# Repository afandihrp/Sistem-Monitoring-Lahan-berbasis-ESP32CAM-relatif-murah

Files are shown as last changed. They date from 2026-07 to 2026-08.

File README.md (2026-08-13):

# Sistem Monitoring Keamanan & Bounding Box AI Berbasis ESP32-CAM & Sensor Getar

Sistem monitoring keamanan pintar berbasis IoT yang mengintegrasikan kamera **ESP32-CAM**, sensor gerak PIR multi-arah, **Node Sensor Getar (Vibration Sensor Node)** dengan kontrol relay HTTP, motor servo pemutar kamera otomatis, kecerdasan buatan (**AI YOLO 11**) untuk deteksi dan pelacakan manusia (*Object Tracking* berbasis *Proportional Controller*), penyimpanan terpusat **SQLite Database**, serta bot Telegram untuk notifikasi instan berupa foto snapshot dan rekaman video MP4.

LINK GITHUB https://github.com/afandihrp/Sistem-Monitoring-Lahan-berbasis-ESP32CAM-relatif-murah.git

---

## 📋 Daftar Isi
1. [Panduan Pengoperasian Sistem (System Operation Guide)](#panduan-pengoperasian-sistem)
   * [1. Autentikasi & Login Pengguna](#1-autentikasi--login-pengguna)
   * [2. Pemilihan Kamera & Feed Live Streaming](#2-pemilihan-kamera--feed-live-streaming)
   * [3. Kontrol Pergerakan Manual Servo (PTZ)](#3-kontrol-pergerakan-manual-servo-ptz)
   * [4. Modal Pengaturan Terpadu (Hardware, PTZ & AI)](#4-modal-pengaturan-terpadu-hardware-ptz--ai)
   * [5. Peninjauan Event Logs & Pemutaran Video Rekaman MP4](#5-peninjauan-event-logs--pemutaran-video-rekaman-mp4)
   * [6. Kontrol & Pengujian Node Sensor Getar](#6-kontrol--pengujian-node-sensor-getar)
   * [7. Penerimaan Notifikasi Peringatan di Bot Telegram](#7-penerimaan-notifikasi-peringatan-di-bot-telegram)
2. [Panduan Instalasi Aplikasi (Server-Side)](#panduan-instalasi-aplikasi)
   * [Instalasi pada Linux (Ubuntu, Linux Mint, Debian)](#1-instalasi-pada-linux-ubuntu-linux-mint--debian-based)
   * [Instalasi pada Windows (Windows 10 / 11)](#2-instalasi-pada-windows-windows-10--11)
   * [Startup Scripts Opsi Cepat (Windows & Linux)](#3-startup-scripts-opsi-cepat-windows-batch--linux-shell)
3. [Setup Hardware & Perkabelan](#setup-hardware-perkabelan)
   * [Pinout ESP32-CAM (AI-Thinker)](#1-pinout-esp32-cam-ai-thinker)
   * [Pinout Node Sensor Getar](#2-pinout-node-sensor-getar-vibration-sensor-node)
   * [Konfigurasi Arduino IDE](#3-konfigurasi-arduino-ide)
   * [Skematik Rangkaian & Desain Hardware Node](#4-skematik-rangkaian--desain-hardware-node)
   * [Dokumentasi Fisik & Realisasi PCB Hardware](#5-dokumentasi-fisik--realisasi-pcb-hardware)
4. [Fitur Utama](#fitur-utama)
   * [Pelacakan Gerakan Otomatis (PIR)](#1-pelacakan-gerakan-otomatis-pir-triggered-servo-rotation)
   * [Node Sensor Getar & HTTP Relay API](#2-node-sensor-getar--http-relay-control-api)
   * [Deteksi Manusia YOLO 11 & P-Controller](#3-deteksi-manusia-yolo-11--pure-proportional-object-tracking)
   * [Mode Sapuan Servo (Sweep & Auto-Return)](#4-mode-sapuan-servo-servo-sweep--auto-return)
   * [Protokol Streaming Biner 16-Bit](#5-protokol-streaming-biner-16-bit--dynamic-chunking)
   * [Penyimpanan Terpusat SQLite Database](#6-penyimpanan-terpusat-sqlite-database-camera_datadb)
   * [Panel Kontrol Kiosk UI Modern](#7-panel-kontrol-kiosk-ui-modern)
   * [Integrasi Bot Telegram & Alert Log](#8-integrasi-bot-telegram--alert-log)
5. [Arsitektur Sistem](#arsitektur-sistem)
6. [Alur Kerja Deteksi Keamanan & Flowchart](#alur-kerja-deteksi-keamanan)
7. [Dokumentasi API & Skema Payload WebSocket](#dokumentasi-api--skema-payload-websocket)
   * [HTTP REST API Endpoint Registry](#1-http-rest-api-endpoint-registry)
   * [Payload WebSocket (ESP32-CAM <-> Backend)](#2-skema-payload-websocket-esp32-cam---backend-nodejs)
   * [Payload WebSocket (Backend <-> Kiosk UI)](#3-skema-payload-websocket-backend-nodejs---kiosk-ui-frontend)
8. [Demo & Tampilan Antarmuka](#demo-tampilan-antarmuka)

---

## 📱 Panduan Pengoperasian Sistem (System Operation Guide)

Panduan langkah demi langkah bagi pengguna akhir (*end-user*) untuk mengoperasikan seluruh antarmuka sistem Kiosk UI, mengontrol perangkat kamera, memutar video rekaman, hingga menerima peringatan keamanan:

---

### 1. Autentikasi & Login Pengguna
1. **Perilaku Autentikasi Berbasis Jaringan (Smart IP-Based Bypass)**:
   * 🟢 **Akses Jaringan Lokal (LAN / Wi-Fi Lokal / Localhost)**:
     * Jika pengguna mengakses portal dari jaringan Wi-Fi/LAN lokal (rentang IP privat `127.0.0.1`, `192.168.x.x`, `10.x.x.x`, atau `172.16-31.x.x`), sistem **secara otomatis membebaskan login** (*Bypass Authentication*). Pengguna akan langsung diarahkan ke Dashboard Pemantauan Utama tanpa perlu memasukkan kata sandi.
   * 🔴 **Akses Jaringan Luar (Tailscale Funnel / VPN Tunneling / IP Publik)**:
     * Jika pengguna mengakses sistem secara *remote* dari luar jaringan lokal menggunakan **Tailscale Funnel** (`runFunnel`), VPN *Tunneling*, atau rute publik eksternal, sistem **secara otomatis mewajibkan autentikasi login** demi mencegah akses tanpa izin.
2. Buka peramban (*browser*) dan akses URL portal sistem:
   * **Akses Nginx (Rekomendasi)**: `http://localhost` (atau IP Lokal server).
   * **Akses Remote Tailscale Funnel**: `https://<subdomain-tailscale-anda>.ts.net`.
   * **Akses Langsung Dev Server**: `http://localhost:5173`.
3. Masukkan kata sandi autentikasi sistem:
   * **Kata Sandi Default**: `admin` (kata sandi bawaan sistem).
   * **Kata Sandi Kustom**: Jika sudah diubah pada file environment `backendAndTelegramBot/.env`, masukkan kata sandi yang dikonfigurasi pada variabel `SYSTEM_PASSWORD` (atau `ADMIN_PASSWORD`).
4. Tekan tombol **Login** untuk menyimpan token autentikasi JWT aman (*HttpOnly Cookie*) dan membuka Dashboard Pemantauan Utama.

| Halaman Autentikasi Kiosk UI |
| :---: |
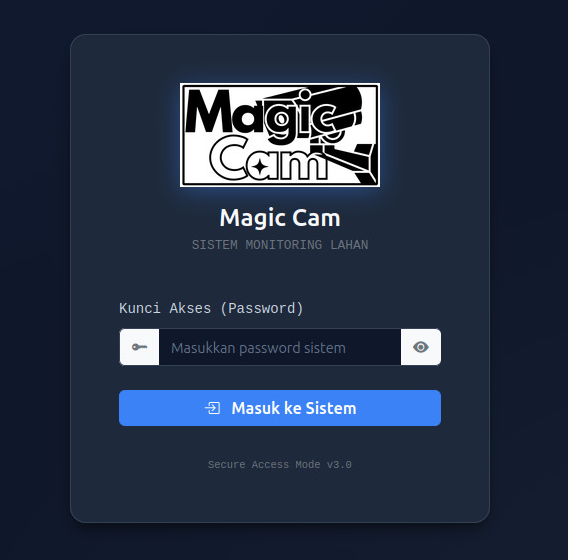
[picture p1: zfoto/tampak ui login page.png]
Tampak UI Login Page
|  |
| *Tampilan Halaman Autentikasi Pengguna (Login Page)* |

---

### 2. Pemilihan Kamera & Feed Live Streaming
1. **Melihat Video Streaming**: Setelah berhasil login, layar utama akan menampilkan tayangan langsung (*Live Stream*) beresolusi optimal dengan rasio 4:3.
2. **Memilih Kamera Aktif**: Jika terdapat lebih dari satu kamera ESP32-CAM terhubung, klik nama/tab kamera pada **Bilah Daftar Kamera (Active Camera List)** di bagian atas atau samping layar untuk berpindah tayangan.
3. **Memantau Indikator Status**:
   * **FPS Meter**: Menampilkan kecepatan *frame rate* per detik secara *real-time* di sudut video.
   * **Indikator Koneksi**: Memantau status hijau (*Connected*) atau merah (*Disconnected*) WebSocket backend gateway.
   * **Hitung Mundur Sapuan Servo**: Menampilkan jeda waktu menuju penyapuan sudut berikutnya.

| Dashboard Pemantauan Desktop | Dashboard Pemantauan Mobile |
| :---: | :---: |
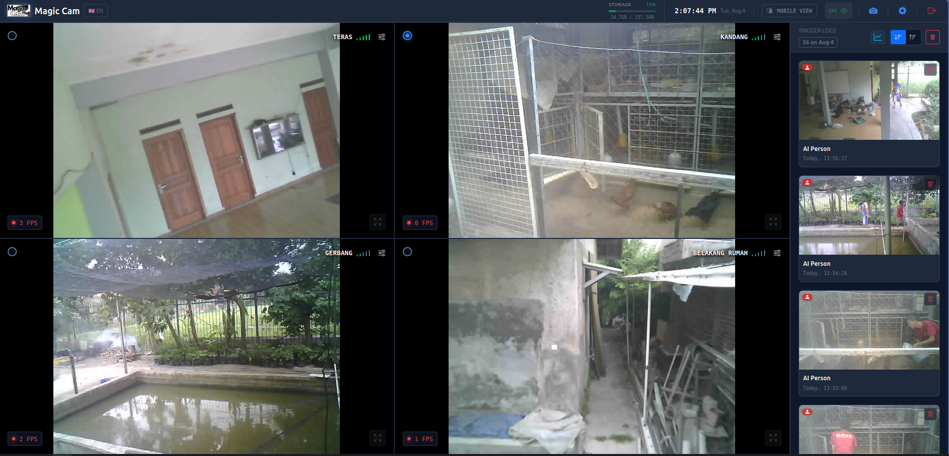
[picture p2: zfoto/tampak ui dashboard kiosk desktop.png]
Tampak UI Dashboard Kiosk Desktop
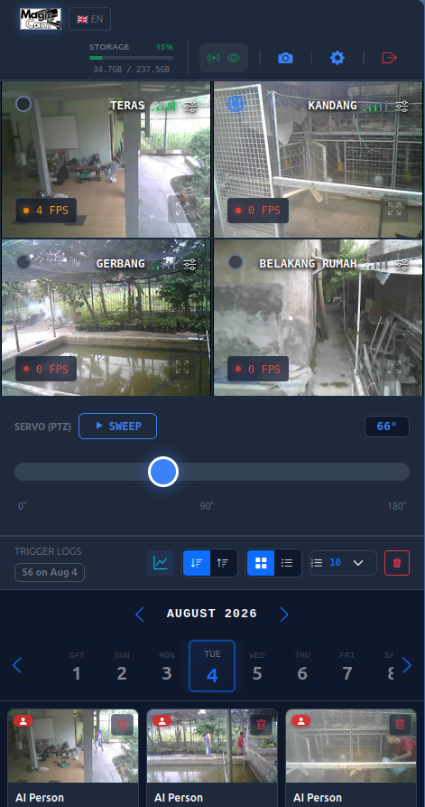
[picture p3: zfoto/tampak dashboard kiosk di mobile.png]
Tampak Dashboard Kiosk di Mobile
|  |  |
| *Dashboard Utama Kiosk UI (Desktop View)* | *Dashboard Utama Kiosk UI (Mobile View)* |

---

### 3. Kontrol Pergerakan Manual Servo (PTZ)
1. **Mengarahkan Kamera**: Gunakan tombol kontrol arah PTZ pada panel antarmuka untuk memutar kamera ESP32-CAM secara manual (sudut $0^\circ$ hingga $180^\circ$).
2. **Penyesuaian Sudut Presisi**: Geser *slider* sudut servo (*tilt/pan slider*) untuk menargetkan posisi pandang tertentu secara fleksibel dan cepat.
3. **Reset Posisi Awal**: Tekan tombol **Default Angle** untuk mengembalikan kamera ke sudut diam standar (misal $90^\circ$).

| Antarmuka Slider Servo Pan/Tilt PTZ |
| :---: |
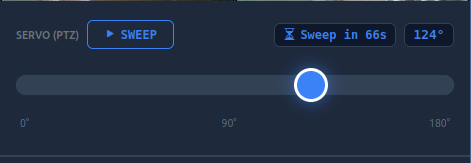
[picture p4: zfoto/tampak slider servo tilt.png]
Tampak Slider Servo Tilt
|  |
| *Tampilan Panel Kontrol Slider Sudut Motor Servo Pan/Tilt pada Kiosk UI* |

---

### 4. Modal Pengaturan Terpadu (Hardware, PTZ & AI)
Klik ikon **Settings (⚙️)** di bagian kanan atas layar untuk membuka modal konfigurasi terpadu:

#### A. Tab Hardware Kamera:
* **Pengaturan Citra**: Sesuaikan tingkat *Brightness* (Kecerahan), *Contrast* (Kontras), dan *Saturation* (Saturasi).
* **Koreksi Otomatis**: Aktifkan/nonaktifkan *Auto White Balance (AWB)* dan *Auto Exposure Control (AEC)*.
* **Efek & Flash**: Pilih *Special Effects* (seperti Grayscale / Negative) dan sesuaikan intensitas lampu sorot LED Flash.
* **Identitas Kamera**: Ubah nama alias lokasi kamera (misal *"Kamera Garasi Depan"*) berdasarkan alamat MAC unik.

#### B. Tab PTZ & Mode Sapuan Servo:
* **Mode Operasi Servo**:
  * **Sweep Mode**: Kamera akan menyapu area pemantauan secara berkala berdasarkan interval waktu.
  * **Auto Return Mode**: Kamera akan kembali ke sudut diam default setelah terpicu gerakan.
* **Timer Interval**: Tentukan interval penyapuan otomatis (misal `15s`, `30s`, atau `Off`).
* **Pemetaan Sudut PIR**: Tentukan sudut kemiringan servo khusus untuk setiap sensor PIR Kiri, Tengah, dan Kanan.

#### C. Tab Konfigurasi AI & Sistem:
* **Deteksi Manusia YOLO 11**: Aktifkan atau nonaktifkan sakelar inferensi AI deteksi manusia secara *real-time*.
* **Ambang Batas Kepercayaan (Confidence Threshold)**: Tentukan batas minimal skor deteksi AI sebelum memicu perekaman video dan notifikasi.

---

### 5. Peninjauan Event Logs & Pemutaran Video Rekaman MP4
1. **Membuka Panel Log Kejadian**: Navigasi ke bagian **Event Logs** di bagian bawah dashboard untuk melihat daftar riwayat kejadian keamanan.
2. **Filter & Detail Kejadian**: Setiap log mencantumkan:
   * Waktu pasti kejadian (*Timestamp*).
   * Jenis pemicu (*PIR Motion Detected*, *Vibration Relay Triggered*, atau *YOLO Human Detected*).
   * Alamat MAC & Nama Kamera sumber.
3. **Melihat Snapshot Foto & Memutar Rekaman Video MP4**:
   * Klik ikon **View Snapshot** untuk melihat foto resolusi tinggi FHD beserta *bounding box* merah tipis (1px) manusia.
   * Klik tombol **Play Video (▶)** pada baris kejadian untuk memutar langsung rekaman video MP4 berdurasi penuh yang di-render secara *asynchronous* oleh backend FFmpeg dari SQLite database `camera_data.db`.

| Tabel Riwayat Kejadian (Event Logs) |
| :---: |
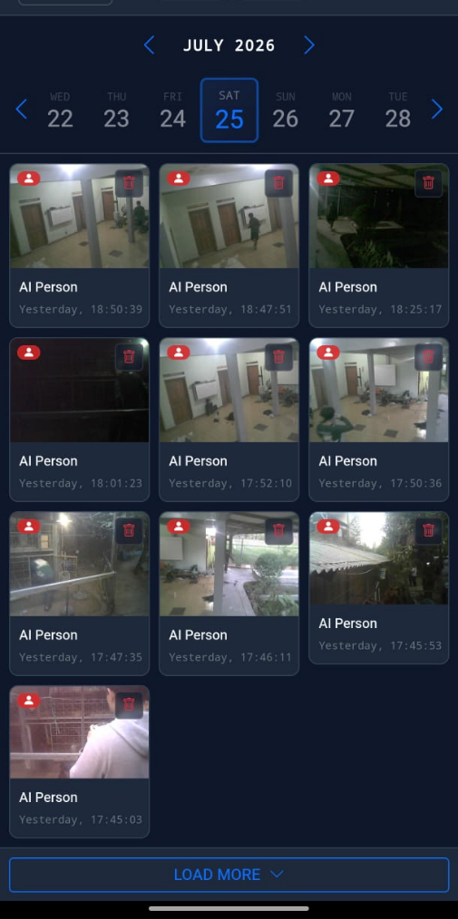
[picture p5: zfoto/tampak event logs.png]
Tampak Event Logs
|  |
| *Tampilan Tabel Riwayat Kejadian Keamanan (Event Logs) pada Kiosk UI* |

| Hasil Snapshot Deteksi Manusia dengan Bounding Box (YOLO 11) |
| :---: |
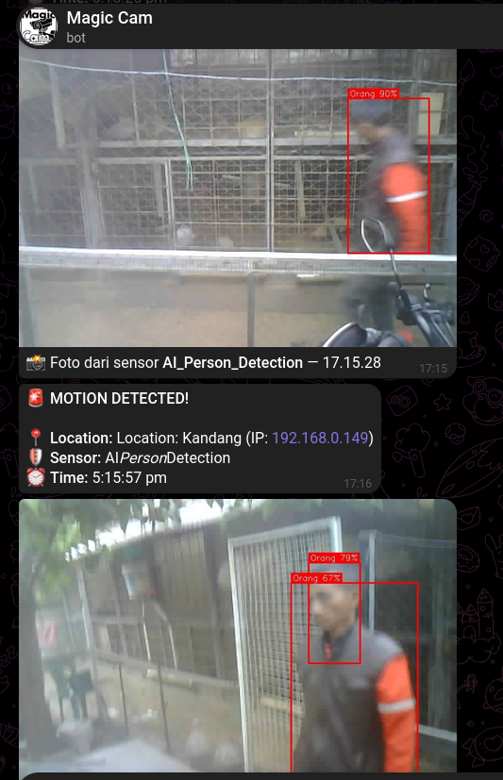
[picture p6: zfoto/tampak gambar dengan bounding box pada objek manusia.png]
Hasil Snapshot Deteksi Bounding Box Manusia
|  |
| *Tampilan Snapshot Hasil Deteksi Manusia YOLO 11 dengan Bounding Box Overlay* |

---

### 6. Kontrol & Pengujian Node Sensor Getar
1. **Pengujian Relay Manual di Kiosk UI**: Tekan tombol **Trigger Relay Test** pada dasbor untuk mengirimkan perintah HTTP GET ke Node Sensor Getar (`vibration_sensor_client`).
2. **Pengujian HTTP Client (cURL / REST Client)**:
   * Untuk menyalakan relay (Active-Low ON):
     ```bash
     curl "http://<IP_NODE_GETAR>/do?relay=1"
     ```
   * Untuk mematikan relay (Active-Low OFF):
     ```bash
     curl "http://<IP_NODE_GETAR>/do?relay=0"
     ```

---

### 7. Penerimaan Notifikasi Peringatan di Bot Telegram
1. **Notifikasi Otomatis**: Saat terjadi ancaman getaran atau manusia terdeteksi oleh AI YOLO 11, Bot Telegram akan secara otomatis memancarkan peringatan instan ke obrolan pengguna.
2. **Review Snapshot & Video**:
   * Pesan Telegram pertama memuat **Foto Snapshot FHD** berisikan *bounding box* subjek manusia.
   * Pesan Telegram kedua memuat **File Video Rekaman MP4** yang dapat langsung diputar secara kontekstual di dalam aplikasi Telegram seluler maupun desktop.

---

## 💻 Panduan Instalasi Aplikasi (Server-Side)

Sistem ini mendukung pengoperasian pada lingkungan **Linux (Ubuntu, Linux Mint, Debian, & OS berbasis Debian/Ubuntu)** serta **Windows (10 / 11)**.

---

### 1. Instalasi pada Linux (Ubuntu, Linux Mint, & Debian-Based)

#### Langkah 1: Instalasi Paket Prasyarat Sistem
Buka Terminal dan jalankan perintah berikut untuk meng-install Node.js, Python, FFmpeg, dan Git:

```bash
# Update paket repository
sudo apt update && sudo apt upgrade -y

# Install Git, Curl, FFmpeg, dan Python3
sudo apt install -y git curl ffmpeg python3 python3-pip python3-venv

# Install Node.js (v18.x LTS via NodeSource)
curl -fsSL https://deb.nodesource.com/setup_18.x | sudo -E bash -
sudo apt install -y nodejs

# Verifikasi instalasi
node -v
npm -v
python3 --version
ffmpeg -version
```

#### Langkah 2: Kloning Repositori
```bash
git clone https://github.com/afandihrp/Sistem-Monitoring-Lahan-berbasis-ESP32CAM-relatif-murah.git
cd projectTaGateway
```

#### Langkah 3: Setup Node.js Backend & Bot Telegram
```bash
cd backendAndTelegramBot
npm install

# Buat file .env di folder backendAndTelegramBot/
echo "TELEGRAM_BOT_TOKEN=8105737525:AAH..." > .env
echo "TELEGRAM_AUTH_PASSWORD=password_anda" >> .env

# Jalankan Backend Server
./runbackend.sh
```
*(Backend beroperasi pada port 3000 dan secara otomatis menginisialisasi SQLite database `camera_data.db`)*

#### Langkah 4: Setup Python AI Detector (YOLO 11)
Buka tab/jendela Terminal baru:
```bash
cd projectTaGateway/human_detection
python3 -m venv pc_env
source pc_env/bin/activate
pip install -r requirements.txt

# Pastikan file model YOLO 11 'best.tflite' ada di folder ini, lalu jalankan:
./start.sh
```

#### Langkah 5: Setup Vue 3 Kiosk UI (Frontend)
Buka tab/jendela Terminal baru:
```bash
cd projectTaGateway/cameraKiosk
npm install
./runkiosk.sh
```
*(Akses dasbor melalui browser di `http://localhost:5173`)*

#### Langkah 6: Setup Nginx Reverse Proxy (Opsional / Direkomendasikan)
Menggunakan konfigurasi Nginx [nginx_configuration/linux/projectTaGateway.conf](file:///home/afandi/Desktop/projectTaGateway/nginx_configuration/linux/projectTaGateway.conf) untuk memetakan Kiosk UI (Port 5173) dan WebSocket API Backend (Port 3000) di bawah Port HTTP standar (Port 80):

```bash
# Install Nginx
sudo apt install -y nginx

# Menyalin file konfigurasi site Nginx untuk Linux
sudo cp projectTaGateway/nginx_configuration/linux/projectTaGateway.conf /etc/nginx/sites-available/projectTaGateway.conf

# Mengaktifkan situs & menghapus situs default (opsional)
sudo ln -s /etc/nginx/sites-available/projectTaGateway.conf /etc/nginx/sites-enabled/
sudo rm -f /etc/nginx/sites-enabled/default

# Uji konfigurasi & restart Nginx
sudo nginx -t
sudo systemctl restart nginx
```
*(Aplikasi kini dapat diakses langsung via browser di `http://localhost` tanpa perlu mengetik nomor port)*

---

### 2. Instalasi pada Windows (Windows 10 / 11)

#### Langkah 1: Instalasi Prasyarat Sistem
1. **Node.js**: Unduh installer **Node.js LTS (v18 atau v20)** dari [nodejs.org](https://nodejs.org/) dan jalankan instalasi.
2. **Python**: Unduh installer **Python 3.9+** dari [python.org](https://www.python.org/).
   * ⚠️ **PENTING**: Centang opsi **"Add python.exe to PATH"** sebelum menekan tombol *Install Now*.
3. **Git**: Unduh installer **Git for Windows** dari [git-scm.com](https://git-scm.com/).
4. **FFmpeg**:
   * **Via Winget (Command Prompt)**: Buka cmd sebagai Administrator dan jalankan `winget install FFmpeg`.
   * **Via Manual**: Unduh *build zip* dari [gyan.dev/ffmpeg/builds/](https://www.gyan.dev/ffmpeg/builds/), ekstrak, dan tambahkan direktori `bin` ke Environment Variables `PATH`.

#### Langkah 2: Kloning Repositori
Buka Command Prompt (cmd) atau PowerShell:
```cmd
git clone https://github.com/afandihrp/Sistem-Monitoring-Lahan-berbasis-ESP32CAM-relatif-murah.git
cd projectTaGateway
```

#### Langkah 3: Setup Node.js Backend & Bot Telegram
```cmd
cd backendAndTelegramBot
npm install

:: Buat file .env
echo TELEGRAM_BOT_TOKEN=8105737525:AAH... > .env
echo TELEGRAM_AUTH_PASSWORD=password_anda >> .env

:: Jalankan Backend Server
runbackend.bat
```

#### Langkah 4: Setup Python AI Detector (YOLO 11)
Buka jendela Command Prompt (cmd) baru:
```cmd
cd projectTaGateway\human_detection
python -m venv pc_env
pc_env\Scripts\activate
pip install -r requirements.txt

:: Jalankan Server AI Detector pada Windows
start.bat
```

#### Langkah 5: Setup Vue 3 Kiosk UI (Frontend)
Buka jendela Command Prompt (cmd) baru:
```cmd
cd projectTaGateway\cameraKiosk
npm install
runkiosk.bat
```
*(Akses dasbor melalui browser di `http://localhost:5173`)*

#### Langkah 6: Setup Nginx Reverse Proxy (Opsional / Direkomendasikan)
1. Unduh **Nginx for Windows** zip dari [nginx.org/en/download.html](https://nginx.org/en/download.html) dan ekstrak (misalnya ke `C:\nginx`).
2. Salin file `nginx.conf` khusus Windows dari folder proyek `projectTaGateway\nginx_configuration\windows\nginx.conf` dan timpa (*overwrite*) file `C:\nginx\conf\nginx.conf`.
3. Jalankan Nginx via Command Prompt (cmd):
   ```cmd
   cd C:\nginx
   start nginx
   ```
4. Perintah pengelolaan Nginx di Windows (cmd):
   ```cmd
   :: Reload konfigurasi Nginx setelah perubahan
   nginx -s reload

   :: Mematikan Nginx
   nginx -s stop
   ```
*(Aplikasi kini dapat diakses langsung via browser di `http://localhost` tanpa perlu mengetik nomor port)*

---

### 3. Startup Scripts Opsi Cepat (Windows Batch & Linux Shell)

Setiap subsistem proyek kini telah dilengkapi dengan script peluncuran lokal masing-masing untuk **Windows (`.bat`)** dan **Linux (`.sh`)**, serta utilitas otomasi publik/browser yang dikelompokkan di dalam folder `start script/`:

| Komponen Subsistem | Lokasi Folder Subsistem | Script Windows (`.bat`) | Script Linux (`.sh`) | Perintah Eksekusi / Fungsi Utama |
| :--- | :--- | :---: | :---: | :--- |
| **Backend Gateway** | `backendAndTelegramBot/` | `runbackend.bat` | `runbackend.sh` | Mengaktifkan server Node.js backend (`npm run dev`) pada Port 3000 |
| **AI Detector (YOLO 11)** | `human_detection/` | `start.bat` | `start.sh` | Mengaktifkan virtual env (`pc_env` / `ai_env`) & server AI (`python app.py`) |
| **Kiosk UI (Frontend)** | `cameraKiosk/` | `runkiosk.bat` | `runkiosk.sh` | Mengaktifkan server dev Vue 3 Kiosk UI (`npm run dev`) pada Port 5173 |
| **Public Funnel (Tailscale)** | `start script/windows/`<br>`start script/linux/` | `runFunnel.bat` | `runFunnel.sh` | Membuka rute HTTPS publik menggunakan `tailscale funnel 80` |
| **Auto Kiosk Browser** | `start script/windows/`<br>`start script/linux/` | `runChromeKiosk.bat` | `runChromeKiosk.sh` | Membuka Google Chrome otomatis dalam mode `--kiosk` fullscreen setelah delay 10s |

#### Cara Menggunakan di Windows:
Jalankan script `.bat` langsung dari dalam folder subsistem masing-masing:
```cmd
:: 1. Jalankan Server Backend Gateway
cd backendAndTelegramBot
runbackend.bat

:: 2. Jalankan Server AI Detector YOLO 11
cd ..\human_detection
start.bat

:: 3. Jalankan Server Kiosk UI Frontend
cd ..\cameraKiosk
runkiosk.bat

:: 4. (Opsional) Jalankan Tailscale Funnel Tunnel
cd "..\start script\windows"
runFunnel.bat

:: 5. (Opsional) Buka Browser Chrome Fullscreen Kiosk Mode
runChromeKiosk.bat
```

#### Cara Menggunakan di Linux (Ubuntu / Mint / Debian):
Jalankan script `.sh` langsung dari dalam folder subsistem masing-masing:
```bash
# 1. Jalankan Server Backend Gateway
cd backendAndTelegramBot
./runbackend.sh

# 2. Jalankan Server AI Detector YOLO 11
cd ../human_detection
./start.sh

# 3. Jalankan Server Kiosk UI Frontend
cd ../cameraKiosk
./runkiosk.sh

# 4. (Opsional) Jalankan Tailscale Funnel Tunnel
cd "../start script/linux"
./runFunnel.sh

# 5. (Opsional) Buka Browser Chrome Fullscreen Kiosk Mode
./runChromeKiosk.sh
```

---

## 🔌 Setup Hardware & Perkabelan

### 1. Pinout ESP32-CAM (AI-Thinker)
| Komponen | Pin Komponen | Pin ESP32-CAM | Deskripsi |
| :--- | :--- | :--- | :--- |
| **PIR Sensor (Kiri)** | OUT / Data | GPIO 13 | Input sinyal gerakan sisi kiri |
| **PIR Sensor (Tengah)** | OUT / Data | GPIO 15 | Input sinyal gerakan sisi tengah |
| **PIR Sensor (Kanan)** | OUT / Data | GPIO 14 | Input sinyal gerakan sisi kanan |
| **Motor Servo** | PWM / Control | GPIO 12 | Sinyal PWM pemutar motor servo |
| **Flash LED** | Onboard LED | GPIO 4 | Lampu sorot flash (Kontrol PWM/LEDC) |

### 2. Pinout Node Sensor Getar (Vibration Sensor Node)
| Komponen | Pin Komponen | Pin ESP32/ESP8266 | Deskripsi |
| :--- | :--- | :--- | :--- |
| **Sensor Getar** | OUT / Data | GPIO 4 (D2) | Sinyal input getaran |
| **Modul Relay** | IN / Signal | GPIO 1 (TX) | Kontrol relay active-low (`LOW` = ON, `HIGH` = OFF) |
| **HTTP API Server** | Port 80 | WebServer.h | Endpoint URL `/do?relay=1` atau `/do?relay=0` |

> [!IMPORTANT]
> **Power Supply Note**: Motor servo dan modul relay memerlukan arus yang stabil. Gunakan **Power Supply Eksternal 5V (Minimal 2A)**. Hubungkan jalur **GND Power Supply Eksternal** dengan **GND ESP32-CAM / Node Sensor** (*Common Ground*).

### 3. Konfigurasi Arduino IDE
1. Buka Arduino IDE dan buka file sketch:
   * Kamera: `camera_client_ws/camera_client_ws.ino` (atau `camera_client_ws_deploy.ino` untuk versi deploy tanpa log serial berlebihan).
   * Node Getar: `vibration_sensor_client/vibration_sensor_client.ino`.
2. Pengaturan Board untuk ESP32-CAM:
   * Board: **AI Thinker ESP32-CAM**
   * PSRAM: **Enabled** (Wajib aktif)
   * Partition Scheme: **Huge APP (3MB No OTA/1MB SPIFFS)**
3. Ubah kredensial Wi-Fi (`ssid` dan `password`) pada sketch.
4. *Compile* dan *Upload* program.

### 4. Skematik Rangkaian & Desain Hardware Node

| Skematik Node Kamera (ESP32-CAM) | Skematik Node Sensor Getar |
| :---: | :---: |
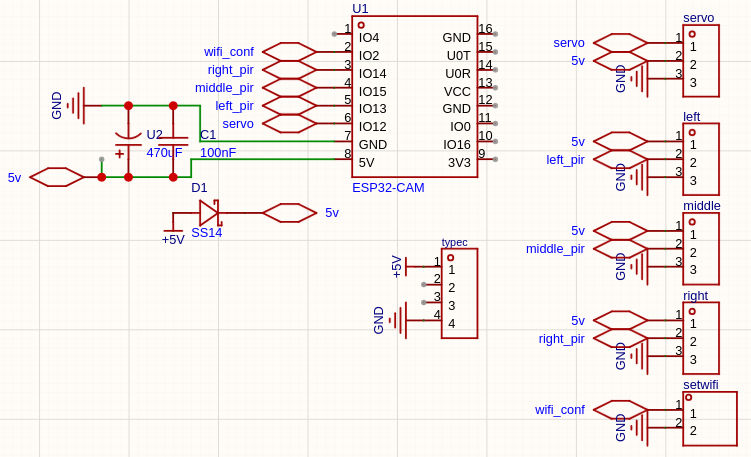
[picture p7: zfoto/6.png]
Skematik Rangkaian Node Kamera
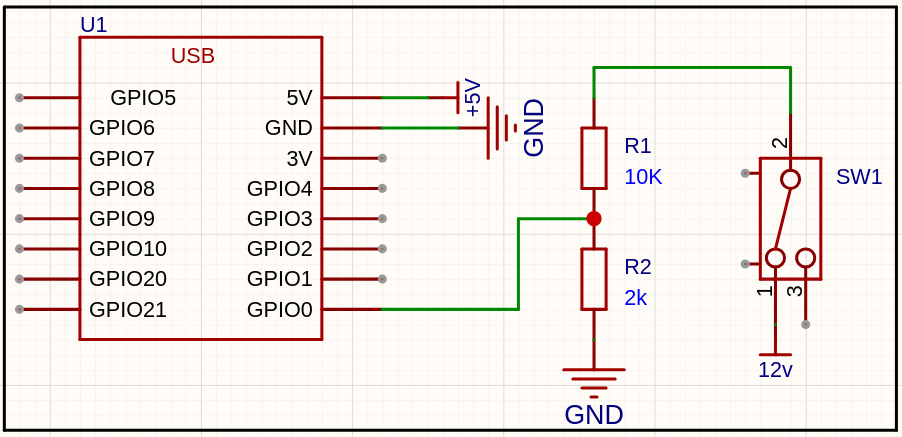
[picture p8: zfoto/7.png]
Skematik Rangkaian Node Sensor Getar
|  |  |
| *Gambar 3.1: Skematik Rangkaian Node Kamera (ESP32-CAM)* | *Gambar 3.9: Skematik Rangkaian Node Sensor Getar* |

<br>

| Desain Enclosure Weatherproof Node Kamera |
| :---: |
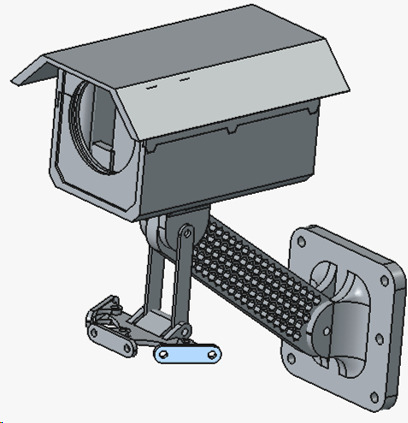
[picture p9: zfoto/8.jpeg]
Desain Enclosure Tahan Cuaca Node Kamera
|  |
| *Gambar 3.2: Desain Enclosure Tahan Cuaca Node Kamera* |

### 5. Dokumentasi Fisik & Realisasi PCB Hardware

| Tampak Depan PCB Custom | Tampak Belakang PCB Custom |
| :---: | :---: |
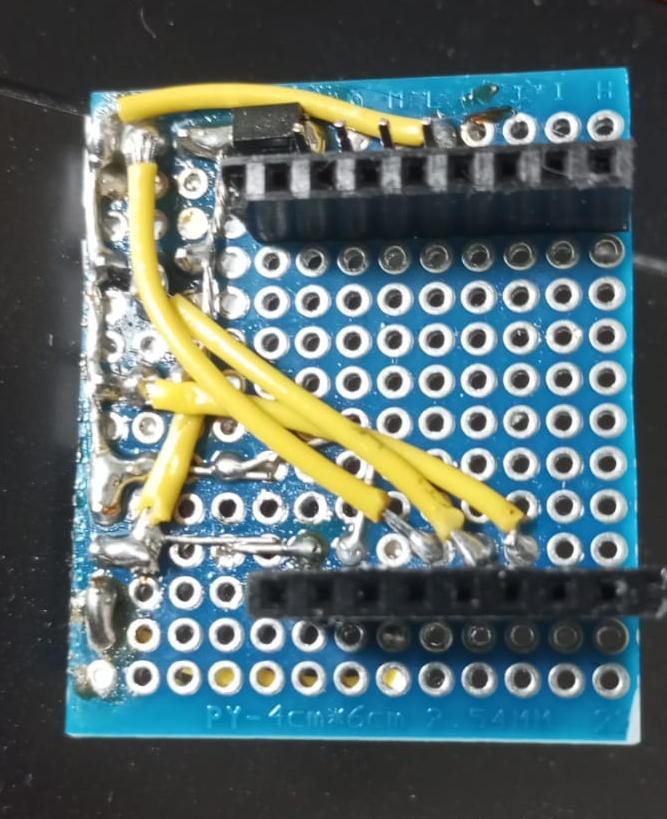
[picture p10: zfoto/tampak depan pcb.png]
Tampak Depan PCB
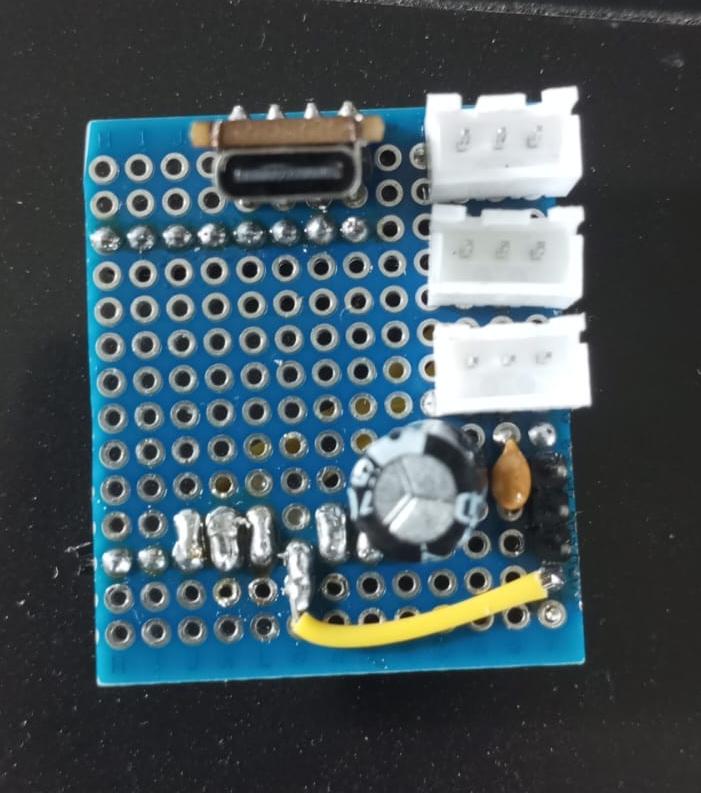
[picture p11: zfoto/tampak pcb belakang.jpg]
Tampak PCB Belakang
|  |  |
| *Tampak Depan PCB Custom Node Kamera* | *Tampak Belakang PCB Custom Node Kamera* |

| Tampilan PCB Terpasang ESP32-CAM | Node Kamera Terpasang di Casing Enclosure |
| :---: | :---: |
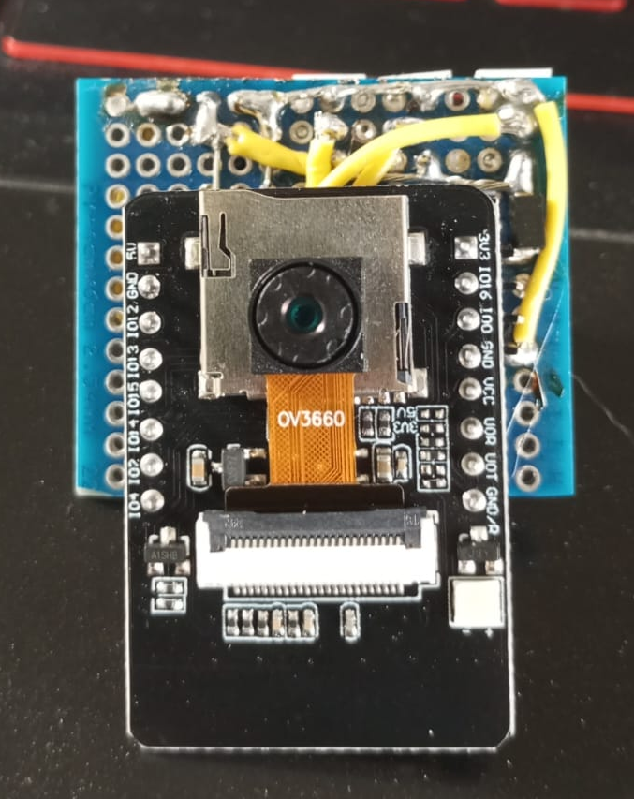
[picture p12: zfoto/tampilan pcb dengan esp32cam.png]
Tampilan PCB dengan ESP32-CAM
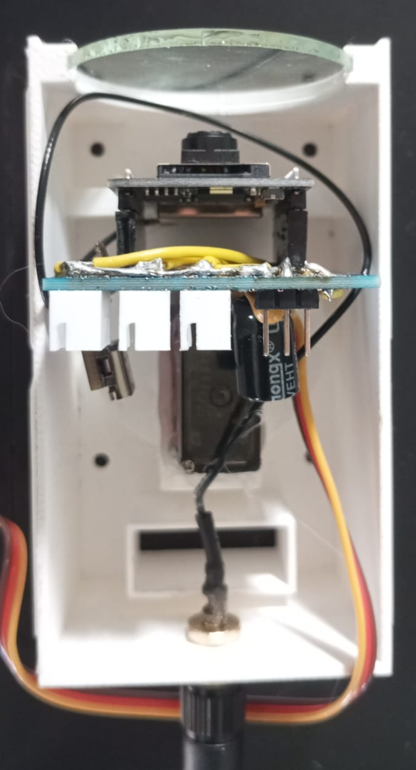
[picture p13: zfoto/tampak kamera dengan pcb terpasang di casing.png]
Tampak Kamera dengan PCB Terpasang di Casing
|  |  |
| *Tampilan PCB Terpasang Modul ESP32-CAM* | *Node Kamera & PCB Terpasang di Casing Enclosure* |

<br>

| Instalasi Sensor Getaran di Pagar Area Lahan |
| :---: |
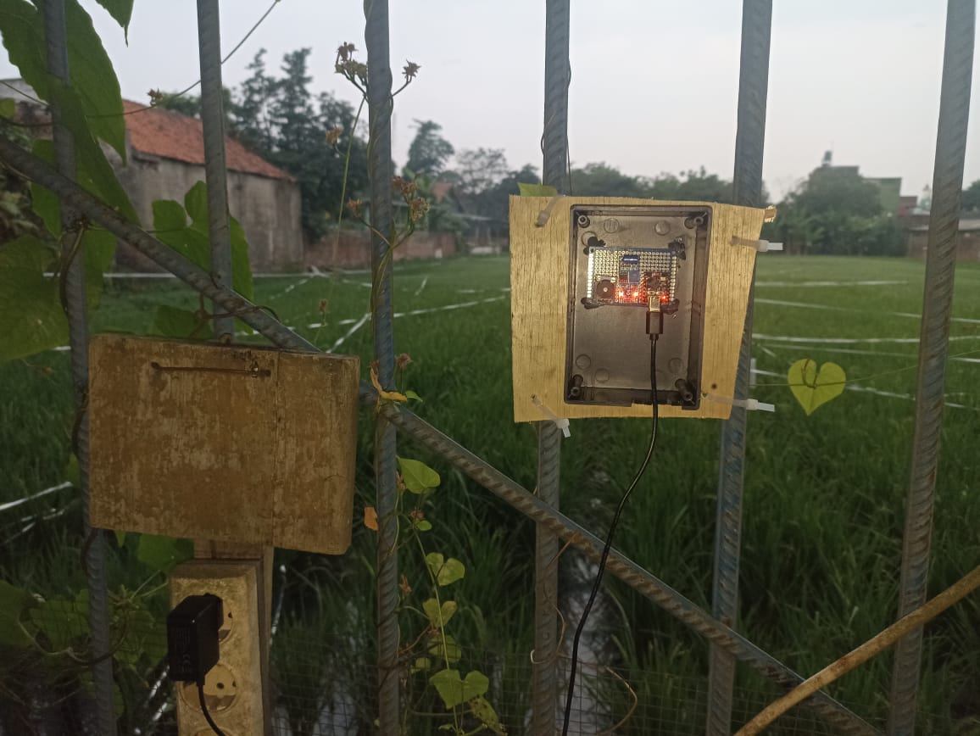
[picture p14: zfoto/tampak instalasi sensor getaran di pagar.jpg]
Tampak Instalasi Sensor Getaran di Pagar
|  |
| *Tampak Instalasi Sensor Getaran pada Pagar Area Pemantauan* |

---

## ⚡ Fitur Utama

### 1. Pelacakan Gerakan Otomatis (PIR-Triggered Servo Rotation)
* Menggunakan 3 sensor PIR (Kiri, Tengah, Kanan) pada ESP32-CAM untuk mendeteksi pergerakan di area sekitar secara presisi.
* Kamera berputar (menggunakan Motor Servo) mengarah ke posisi sensor PIR yang aktif, dengan pengiriman status WebSocket yang ditunda hingga gerakan servo selesai mencapai sudut target.

### 2. Node Sensor Getar & HTTP Relay Control API
* Mengintegrasikan node independen **Sensor Getar** (`vibration_sensor_client.ino`) berbasis ESP32/ESP8266.
* Menyediakan API HTTP Server pada Port 80 untuk mengontrol relay eksternal (`GET /do?relay=1` untuk ON dan `GET /do?relay=0` untuk OFF).
* Menggunakan pinout *Active-Low* (GND) untuk pemicuan relay yang aman dan stabil.

### 3. Deteksi Manusia YOLO 11 & Pure Proportional Object Tracking
* **Model YOLO 11 (`best.tflite`)**: Inferensi cepat dengan dukungan akelerasi **OpenVINO (Intel iGPU)** serta *fallback* CPU.
* **Pure Proportional (P) Controller**: Algoritma pelacakan objek di [objectFollower.js](file:///home/afandi/Desktop/projectTaGateway/backendAndTelegramBot/src/services/objectFollower.js) menggunakan pengontrol proporsional yang ringan, bebas *state*, dan *jitter-free* ($K_p = 45$, *deadband* $0.10$). Motor servo merespons posisi *bounding box* manusia secara halus untuk menjaga posisi subjek di tengah bidang pandang kamera.

### 4. Mode Sapuan Servo (Servo Sweep & Auto-Return)
* **Pilihan Mode Servo**: Mode *Sweep* (penyapuan berkala) atau *Auto-Return* (kembali ke sudut default).
* **Hitung Mundur Cerdas**: Penjadwalan hitung mundur ditampilkan di Kiosk UI (`nextTimerTime`). Sapuan otomatis ditangguhkan secara instan jika PIR atau AI mendeteksi manusia, dan berlanjut secara otomatis saat area kembali aman.
* Kecepatan sapuan diatur halus di firmware ESP32-CAM (250ms per derajat).

### 5. Protokol Streaming Biner 16-Bit & Dynamic Chunking
* Transmisi frame biner menggunakan paket header 16-bit Big-Endian (total 6 byte header + payload chunk).
* **Penyesuaian Chunk Dinamis**: ESP32-CAM mengevaluasi sinyal Wi-Fi (RSSI) secara *real-time*. Jika RSSI < -55dBm, ukuran paket chunk diturunkan secara otomatis dari 1024 byte menjadi 512 byte untuk mencegah kemacetan paket data.

### 6. Penyimpanan Terpusat SQLite Database (`camera_data.db`)
* Menggantikan file konfigurasi JSON lama dengan **SQLite Database** terintegrasi.
* Menyimpan profil konfigurasi hardware kamera/servo per alamat MAC (`device_configs`) dengan fitur *auto-migration schema* dan *fallback default values*, serta menyimpan riwayat log kejadian (*event log*).

### 7. Panel Kontrol Kiosk UI Modern
* Antarmuka web modern (Vue 3 + Tailwind CSS) dengan **Modal Pengaturan Bertab** (*Hardware Settings* dan *PTZ & Sweep Settings*).
* Penamaan kamera berbasis alamat MAC, pengukur FPS murni *client-side* (tersimpan di *LocalStorage*), indikator kesehatan *bandwidth*, dan kontainer video rasio 4:3 yang responsif untuk tampilan *mobile*.

### 8. Integrasi Bot Telegram & Alert Log
* Mengirimkan peringatan instan ke pengguna Telegram terautentikasi.
* Notifikasi memuat **Foto Snapshot Resolusi Tinggi (FHD)** berisikan *bounding box* hasil deteksi AI, beserta **Video MP4** rekaman kejadian yang di-render secara *asynchronous* menggunakan FFmpeg.

---

## 🏗 Arsitektur Sistem

Sistem ini terdiri dari komponen-komponen terintegrasi yang saling berkomunikasi melalui protokol jaringan berlatensi rendah:

```
+---------------------+         WebSocket (16-bit Chunks)        +----------------------+
|  ESP32-CAM Client   |----------------------------------------->|                      |
| (PIR 3x, Servo PTZ) |<-----------------------------------------|                      |
+---------------------+            Config & Commands             |    Node.js Server    |
                                                                 |    (Backend Gateway) |
+---------------------+           HTTP GET /do?relay=1/0         |                      |
| Node Sensor Getar   |----------------------------------------->|                      |
| (Relay Control API) |                                          +----------------------+
+---------------------+                                            |   ^            |
                                                      TCP Binary   |   |            | WebSocket
                                                      Frame Stream v   |            v & HTTP
                                                            +--------------+   +--------------------+
                                                            |  Python AI   |   | Vue 3 Kiosk UI     |
                                                            | (YOLO 11)    |   | Dashboard Frontend |
                                                            +--------------+   +--------------------+
                                                                                    |
                                                                                    v
                                                                          +--------------------+
                                                                          | SQLite Database    |
                                                                          | (camera_data.db)   |
                                                                          +--------------------+
```

### Visualisasi Arsitektur & Topologi Sistem

| Diagram Blok Keseluruhan | Desain Arsitektur Jaringan |
| :---: | :---: |
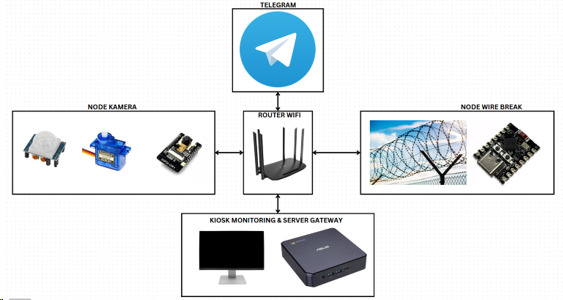
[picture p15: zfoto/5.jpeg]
Diagram Blok Keseluruhan Sistem
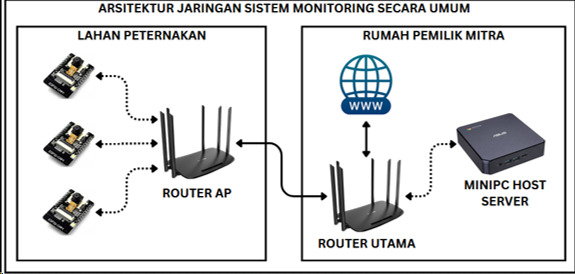
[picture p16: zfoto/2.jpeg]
Desain Arsitektur Jaringan
|  |  |
| *Gambar 3.16: Diagram Blok Keseluruhan Sistem* | *Gambar 3.17: Desain Arsitektur Jaringan* |

| Desain Aliran Data (Dataflow) | Denah Pantauan Kamera |
| :---: | :---: |
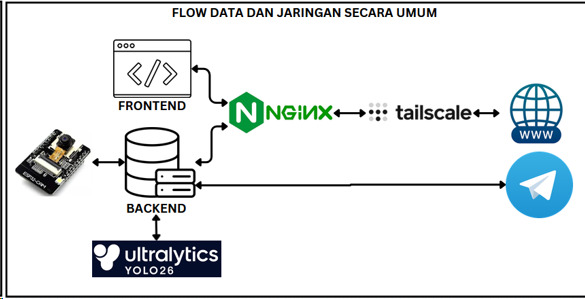
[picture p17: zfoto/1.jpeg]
Desain Aliran Data dan Integrasi Sistem
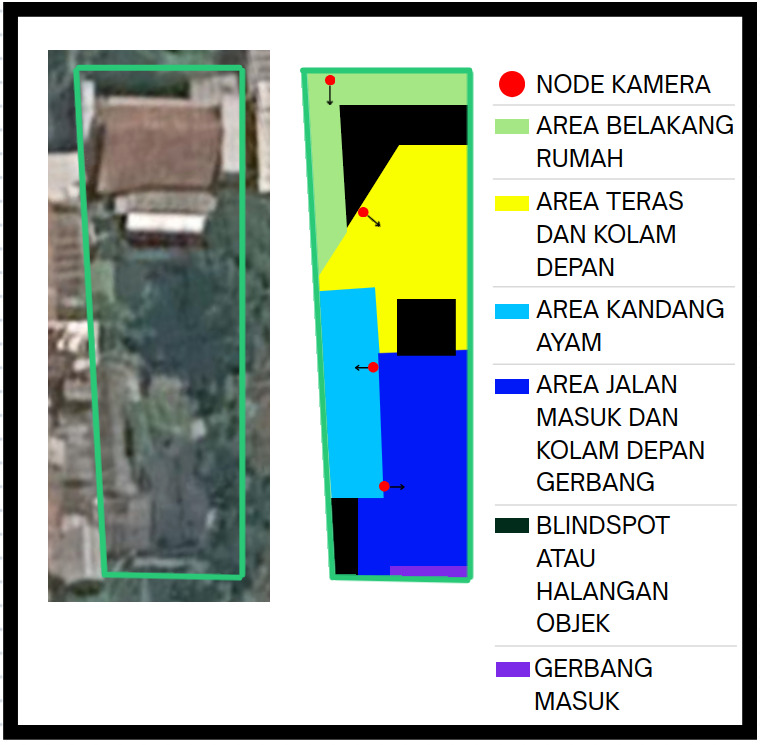
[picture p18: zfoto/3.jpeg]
Denah Pantauan Kamera
|  |  |
| *Gambar 3.18: Desain Aliran Data dan Integrasi Sistem* | *Gambar 3.10: Denah Pantauan Kamera* |

---

## 🔄 Alur Kerja Deteksi Keamanan & Flowchart

### Flowchart Sistem Utama (Mermaid)

```mermaid
flowchart TD
    subgraph Hardware_Layer["Hardware Layer (ESP32 Nodes)"]
        PIR["Sensor PIR (Kiri/Tengah/Kanan)"]
        VIB["Node Sensor Getar (HTTP Relay API)"]
        CAM["Kamera ESP32-CAM (MJPEG Stream)"]
        SERVO["Motor Servo PTZ"]
    end

    subgraph Backend_Gateway["Node.js Backend Gateway"]
        WS["WebSocket Gateway & Router"]
        P_CTRL["Pure Proportional (P) Controller"]
        DB[("SQLite Database (camera_data.db)")]
        REC["FFmpeg Video Buffer & MP4 Renderer"]
        BOT["Telegram Bot Notifier"]
    end

    subgraph AI_Subsystem["Python AI Subsystem"]
        YOLO["Detector (YOLO 11 TFLite / OpenVINO)"]
    end

    subgraph Frontend_Kiosk["Vue 3 Kiosk Dashboard"]
        UI["Live Monitoring & Control Panel"]
    end

    PIR -->|"Trigger Gerakan"| CAM
    VIB -->|"HTTP GET /do?relay=1"| WS
    CAM -->|"16-bit Chunked Stream (UDP/WS)"| WS
    WS -->|"Video Frames"| UI
    WS -->|"Frame Feed"| YOLO
    YOLO -->|"Bounding Box Coordinates"| WS
    WS -->|"Koordinat Bounding Box"| P_CTRL
    P_CTRL -->|"Command Sudut Servo"| SERVO
    WS -->|"Event Trigger"| REC
    REC -->|"Simpan MP4 & Log"| DB
    REC -->|"Snapshot + Video MP4"| BOT
    BOT -->|"Notifikasi Peringatan"| USER["User (Aplikasi Telegram)"]
    UI -->|"Simpan Parameter / PTZ Manual"| DB
```

### Penjelasan Alur Kerja

1. **Deteksi Gerakan Awalan**:
   * Sensor PIR mendeteksi pergerakan di area Kiri, Tengah, atau Kanan $\rightarrow$ Servo memutar kamera ke sudut sensor terkait.
   * Atau **Node Sensor Getar** menerima getaran fisik $\rightarrow$ Memicu relai dan memancarkan request HTTP ke backend gateway.
2. **Pengiriman Stream & Inferensi AI**:
   * ESP32-CAM mengirimkan paket frame biner melalui protokol WebSocket 16-bit.
   * Backend Node.js meneruskan frame ke **Python AI Subsystem** (YOLO 11).
3. **Pelacakan Objek (Object Tracking)**:
   * Jika manusia terdeteksi, koordinat *bounding box* dikirim ke `objectFollower.js`.
   * **P-Controller** menghitung `deltaAngle = offset * Kp` dan menggerakkan servo untuk menjaga manusia tepat di tengah layar.
4. **Perekaman Video & Notifikasi Telegram**:
   * Backend mengumpulkan frame ke *rolling buffer*. Saat objek menghilang, FFmpeg me-render video MP4 secara *asynchronous*.
   * Notifikasi memuat foto snapshot resolusi tinggi dan rekaman MP4 dikirimkan ke Telegram pengguna serta dicatat pada database SQLite `camera_data.db`.

---

## 🌐 Dokumentasi API & Skema Payload WebSocket

### 1. HTTP REST API Endpoint Registry

#### A. Backend Gateway Server (Port 3000)
| Endpoint | Method | Hak Akses | Deskripsi & Fungsionalitas | Contoh Request Payload | Contoh Response Output |
| :--- | :---: | :---: | :--- | :--- | :--- |
| `/api/login` | `POST` | Publik | Autentikasi pengguna Kiosk UI | `{"password": "123"}` | `{"success": true, "message": "Logged in successfully"}` |
| `/api/logout` | `POST` | Session | Logout session & hapus cookie auth | `-` | `{"success": true}` |
| `/api/verify` | `GET` | Cookie/IP | Verifikasi status autentikasi session / IP Lokal | `-` | `{"success": true, "local": true, "authenticated": true}` |
| `/upload` | `POST` | ESP32 | High-Res FHD Image upload dari ESP32-CAM | `Raw Binary JPEG Buffer` | `{"status": "ok", "file": "snapshot-1722..."}` |
| `/api/ping` | `GET` | Publik | Health-check endpoint gateway backend | `-` | `{"status": "pong", "timestamp": 1722800000000}` |

#### B. Node Sensor Getar (Port 80)
| Endpoint | Method | Deskripsi | Query Parameters | Contoh Request URL | Respon Output |
| :--- | :---: | :--- | :--- | :--- | :--- |
| `/do` | `GET` | Kontrol HTTP Relay Active-Low | `relay=1` (ON) / `relay=0` (OFF) | `http://192.168.1.50/do?relay=1` | `HTTP 200 OK (Relay ON)` |

---

### 2. Skema Payload WebSocket (ESP32-CAM <-> Backend Node.js)

#### A. Pesan dari ESP32-CAM ke Backend:
* **Heartbeat Keep-Alive (Pong)**:
  ```json
  { "type": "pong" }
  ```
* **Status Sinyal PIR Motion**:
  ```json
  {
    "type": "motion",
    "sensor": "pir_left"
  }
  ```
* **Status Selesai Menyapu (Sweep Completed)**:
  ```json
  {
    "type": "sweep_status",
    "value": "off"
  }
  ```

#### B. Pesan dari Backend ke ESP32-CAM:
* **Kontrol Pergerakan Servo (PTZ)**:
  ```json
  {
    "type": "servo_control",
    "value": 90
  }
  ```
* **Kontrol Sapuan Servo (Sweep)**:
  ```json
  {
    "type": "sweep_control",
    "value": "once"
  }
  ```
* **Update Konfigurasi Hardware Kamera**:
  ```json
  {
    "type": "camera_config_update",
    "config": {
      "brightness": 0,
      "contrast": 0,
      "saturation": 0,
      "awb": 1,
      "aec": 1,
      "framesize": 6,
      "flashIntensity": 50
    }
  }
  ```

---

### 3. Skema Payload WebSocket (Backend Node.js <-> Kiosk UI Frontend)

#### A. Pesan Broadcast Backend ke Kiosk UI:
* **Daftar Perangkat Terhubung (`device_list`)**:
  ```json
  {
    "type": "device_list",
    "devices": [
      {
        "id": "A4:CF:12:89:56:4C",
        "ip": "192.168.1.100",
        "name": "Kamera Garasi Kiri",
        "type": "Camera",
        "currentAngle": 90,
        "sweepActive": "off",
        "nextTimerTime": 1722800015000,
        "servoMode": "sweep"
      }
    ]
  }
  ```
* **Broadcast Bounding Box Deteksi AI (`stream_boxes`)**:
  ```json
  {
    "type": "stream_boxes",
    "deviceId": "A4:CF:12:89:56:4C",
    "boxes": [
      {
        "confidence": 0.92,
        "posisi": [0.15, 0.20, 0.45, 0.85]
      }
    ]
  }
  ```
* **Perubahan Stream Aktif (`active_stream_updated`)**:
  ```json
  {
    "type": "active_stream_updated",
    "deviceId": "A4:CF:12:89:56:4C"
  }
  ```
* **Real-Time Event Log (`motion_event`)**:
  ```json
  {
    "type": "motion_event",
    "deviceId": "A4:CF:12:89:56:4C",
    "event": "PIR Motion Detected (PIR Left)",
    "timestamp": 1722800000000
  }
  ```

#### B. Pesan Kontrol dari Kiosk UI ke Backend:
* **Mengganti Kamera Aktif (`set_active_stream`)**:
  ```json
  {
    "type": "set_active_stream",
    "deviceId": "A4:CF:12:89:56:4C"
  }
  ```
* **Menyimpan Konfigurasi Servo & PTZ (`save_servo_config`)**:
  ```json
  {
    "type": "save_servo_config",
    "mac": "A4:CF:12:89:56:4C",
    "config": {
      "servoMode": "sweep",
      "servoTimer": "15s",
      "defaultAngle": 90,
      "leftPirAngle": 45,
      "middlePirAngle": 90,
      "rightPirAngle": 135
    }
  }
  ```
* **Menyimpan Konfigurasi Hardware Kamera (`save_camera_config`)**:
  ```json
  {
    "type": "save_camera_config",
    "mac": "A4:CF:12:89:56:4C",
    "config": {
      "name": "Kamera Depan Kandang",
      "brightness": 1,
      "contrast": 0,
      "specialEffect": "None"
    }
  }
  ```

---

## 📸 Demo & Tampilan Antarmuka

### 1. Antarmuka Kiosk UI & Dashboard Pemantauan

| Halaman Login Kiosk UI |
| :---: |
| Tampak UI Login Page |
| *Halaman Autentikasi Pengguna (Login Page)* |

| Dashboard Pemantauan Desktop (Desktop View) | Dashboard Pemantauan Mobile (Mobile View) |
| :---: | :---: |
| Tampak UI Dashboard Kiosk Desktop | Tampak Dashboard Kiosk di Mobile |
| *Dashboard Pemantauan Utama Kiosk UI (Desktop View)* | *Dashboard Pemantauan Utama Kiosk UI (Mobile View)* |

| Panel Kontrol Slider Servo Pan/Tilt PTZ | Tabel Riwayat Kejadian (Event Logs) |
| :---: | :---: |
| Tampak Slider Servo Tilt | Tampak Event Logs |
| *Tampilan Panel Kontrol Slider Sudut Servo PTZ* | *Tampilan Tabel Riwayat Kejadian Keamanan (Event Logs)* |

### 2. Deteksi Manusia AI & Bounding Box Overlay

| Hasil Snapshot Deteksi Manusia dengan Bounding Box (YOLO 11) |
| :---: |
| Hasil Snapshot Deteksi Bounding Box Manusia |
| *Hasil Snapshot Foto Resolusi Tinggi dengan Overlay Bounding Box Merah Tipis (1px) Hasil Inferensi YOLO 11* |

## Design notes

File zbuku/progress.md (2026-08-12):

# Gateway Progress Log

- **2026-08-12**: Removed synchronizing loading animation from EventLogs.vue
  - Logic/Hardware changed: Removed UI spinner in `EventLogs.vue`.
  - Side effects: Cleaner UI.
  - Next steps: None currently.
- **2026-08-12**: Fixed event log fetching bug
  - Logic/Hardware changed: Imported `getLogsByDate` missing in `websocket.js`.
  - Side effects: Restored `fetch_historical_logs` functionality.
  - Next steps: Verify real-time logs.
- **2026-08-12**: Fixed broken Analytics Modal statistics
  - Logic/Hardware changed: Shifted analytics computation to backend. Added `getAnalyticsSummary` in `sqllite_logger.js`, `fetch_analytics` socket in `websocket.js`. Refactored `AnalyticsModal.vue` and `KioskDashboard.vue` to fetch and use server-side `analyticsData`.
  - Side effects: "Month", "Year", and "All" analytics now work accurately despite the previous lazy-loading optimization.
  - Next steps: Verify charts render properly.

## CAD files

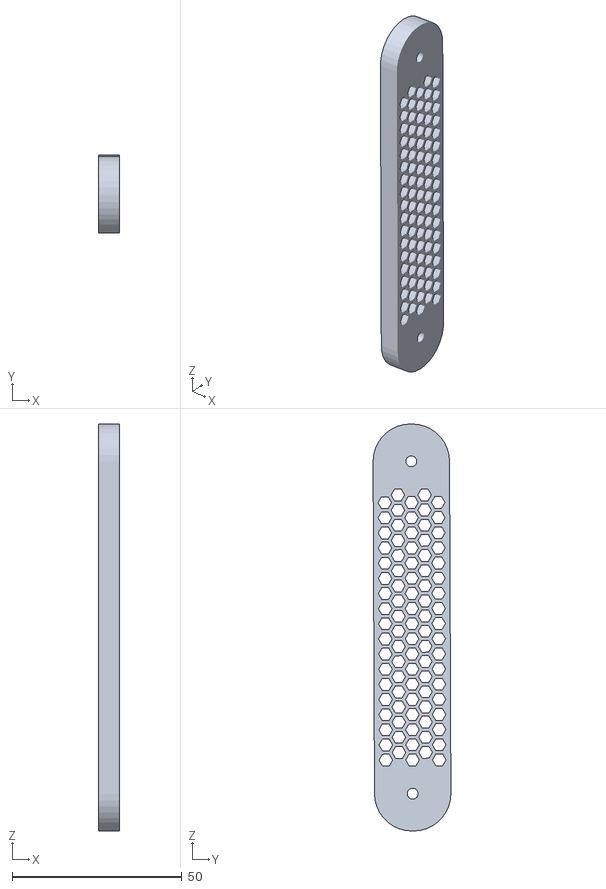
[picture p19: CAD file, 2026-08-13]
file 3d model casing/cctvv3-shaft_mounting_camera (Solid).stl
6.30 x 23.0 x 120.0

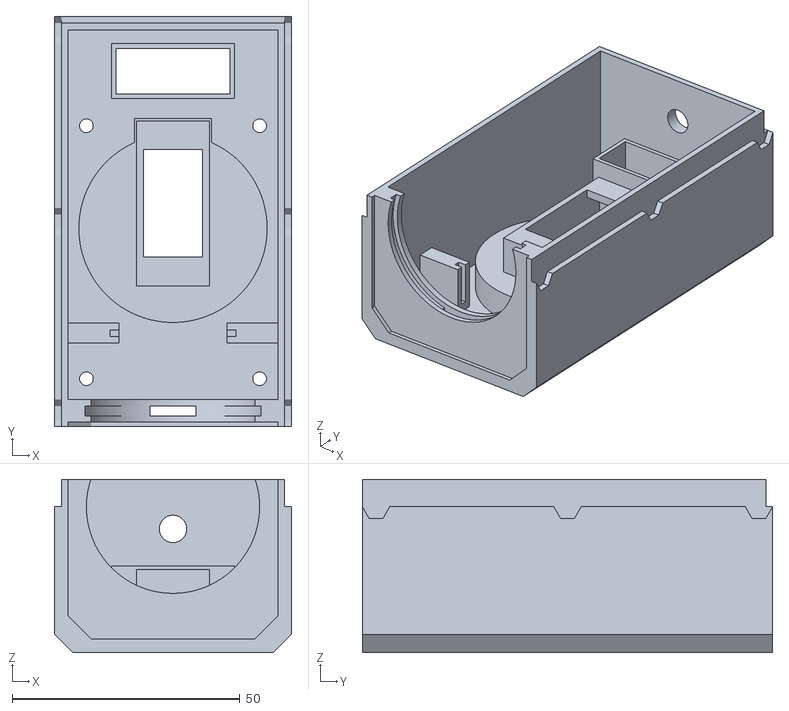
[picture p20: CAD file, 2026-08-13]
file 3d model casing/cctvv3-bottom case001 (Solid).stl
52.0 x 90.0 x 38.0

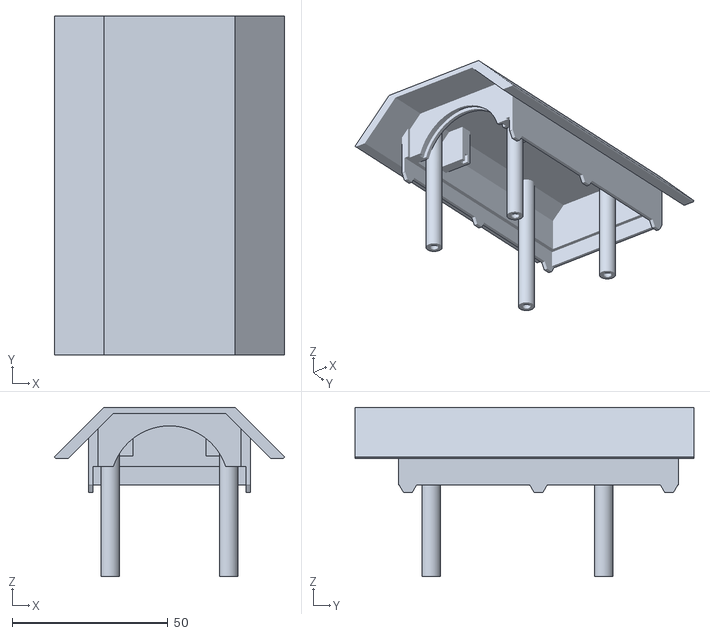
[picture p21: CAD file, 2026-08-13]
file 3d model casing/cctvv3-top case001 (Solid).stl
74.0 x 109.0 x 54.5

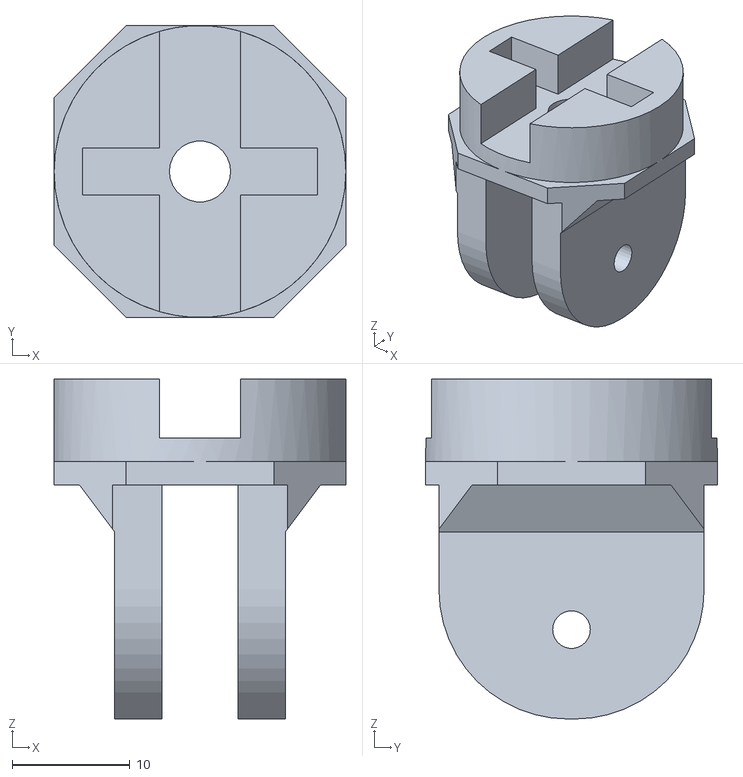
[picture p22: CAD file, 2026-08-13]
file 3d model casing/cctvv3-servo mount.stl
24.8 x 24.8 x 28.9

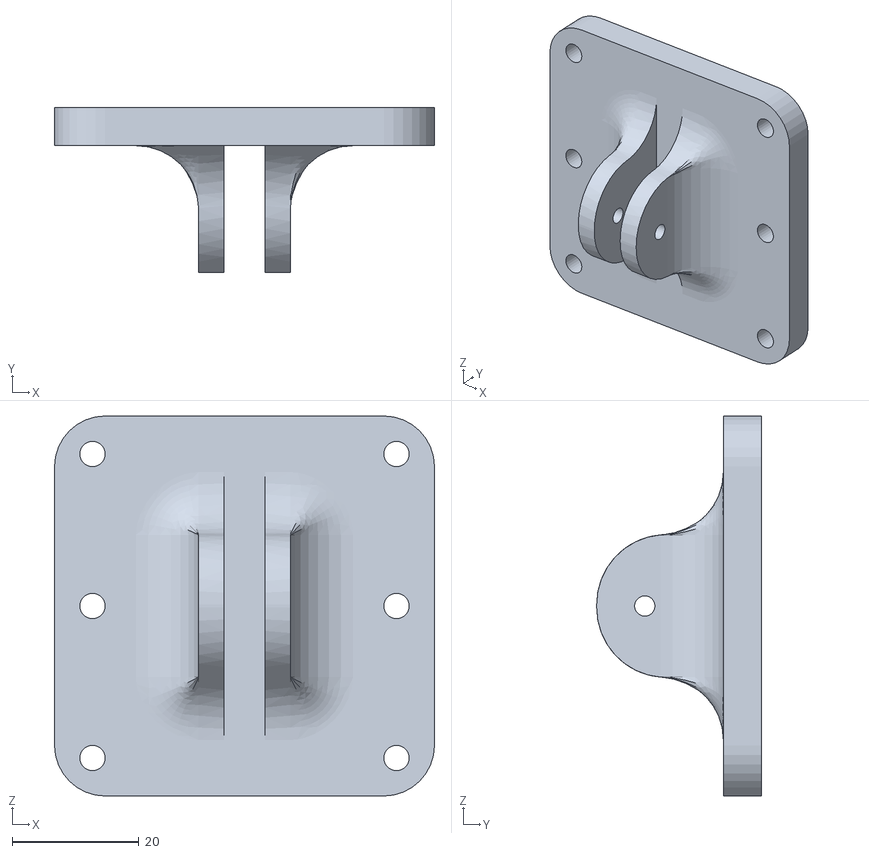
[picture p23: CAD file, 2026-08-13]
file 3d model casing/cctvv3-mouting_wall_camera.stl
60.0 x 26.0 x 60.0

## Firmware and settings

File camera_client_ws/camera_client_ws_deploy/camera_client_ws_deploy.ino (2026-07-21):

#include <WiFi.h>
#include <WebSocketsClient.h>
#include <HTTPClient.h>
#include "esp_camera.h"
#include "soc/soc.h"
#include "soc/rtc_cntl_reg.h"
#include <WiFiManager.h>
#include <WiFiUdp.h>
#include <Preferences.h>

// AI Thinker ESP32-CAM Pinout
#define PWDN_GPIO_NUM     32
#define RESET_GPIO_NUM    -1
#define XCLK_GPIO_NUM      0
#define SIOD_GPIO_NUM     26
#define SIOC_GPIO_NUM     27
#define Y9_GPIO_NUM       35
#define Y8_GPIO_NUM       34
#define Y7_GPIO_NUM       39
#define Y6_GPIO_NUM       36
#define Y5_GPIO_NUM       21
#define Y4_GPIO_NUM       19
#define Y3_GPIO_NUM       18
#define Y2_GPIO_NUM        5
#define V_SYNC_GPIO_NUM   25
#define H_REF_GPIO_NUM    23
#define P_CLK_GPIO_NUM    22

// Servo Configuration
#define SERVO_PIN 12
#define SERVO_LEDC_RES 13 // 13-bit resolution (8192)
#define SERVO_LEDC_FREQ 50 // 50Hz for standard servos

// Servo Positions
uint8_t SERVO_POS_LEFT = 155;
uint8_t SERVO_POS_MIDDLE = 90;
uint8_t SERVO_POS_RIGHT = 0;
uint8_t SERVO_POS_DEFAULT = 90;

// WiFi credentials managed by WiFiManager

// Security API Key
const char* apiKey = "momo_gemoy_api_key_123";

const uint8_t left_pir_pin = 13;
const uint8_t middle_pir_pin = 15;
const uint8_t right_pir_pin = 14;

volatile bool pendingLeftMotion = false;
volatile bool pendingMiddleMotion = false;
volatile bool pendingRightMotion = false;

// Flash LED GPIO (AI Thinker ESP32-CAM: GPIO 4)
#define FLASH_GPIO_NUM 4

// LED Notification states
enum LedNotificationState {
  LED_STATE_OFF = 0,
  LED_STATE_CONNECTING_WIFI = 1,
  LED_STATE_FINDING_SERVER = 2
};
volatile int ledNotificationState = LED_STATE_OFF;

// Flag untuk on-demand capture via Telegram
String pendingCaptureLabel = "";

// Flag untuk servo control
volatile int pendingServoAngle = -1;

volatile bool pendingConnectionRestart = false;

volatile int currentServoAngle = 90;
volatile int targetServoAngle = 90;
volatile int sweepMode = 0; // 0 = off, 1 = continuous, 2 = once
volatile bool sweepDirectionUp = true;
volatile bool sweepReturning = false;
volatile bool pendingSweepStopReport = false;
TaskHandle_t servoTaskHandle = NULL;

// Global camera config agar bisa dipakai ulang saat reinit
camera_config_t app_cam_config;

// Camera Configurator Parameters (defaults matching backend startup)
String cam_resolution = "HVGA";
int cam_quality = 12;
int cam_brightness = 0;
int cam_contrast = 0;
int cam_saturation = 0;
bool cam_awb = true;
bool cam_aec = true;
bool cam_agc = true;
bool cam_hmirror = false;
bool cam_vflip = false;
String cam_specialEffect = "None";
int cam_xclk = 8000000;
bool cam_flashOnCapture = true;
int cam_flashIntensity = 0;

// PIR sensor settings managed by backend system settings
bool cam_pirEnabled = true;
int cam_pirCooldown = 30;
unsigned long lastPirTriggerTime = 0;

void applyCameraConfig() {
  sensor_t * s = esp_camera_sensor_get();
  if (!s) return;

  // 1. Resolution
  framesize_t framesize = FRAMESIZE_HVGA;
  if (cam_resolution == "UXGA") framesize = FRAMESIZE_UXGA;
  else if (cam_resolution == "SVGA") framesize = FRAMESIZE_SVGA;
  else if (cam_resolution == "VGA") framesize = FRAMESIZE_VGA;
  else if (cam_resolution == "CIF") framesize = FRAMESIZE_CIF;
  else if (cam_resolution == "HVGA") framesize = FRAMESIZE_HVGA;
  else if (cam_resolution == "QVGA") framesize = FRAMESIZE_QVGA;
  else if (cam_resolution == "HQVGA") framesize = FRAMESIZE_HQVGA;
  else if (cam_resolution == "QCIF") framesize = FRAMESIZE_QCIF;
  else if (cam_resolution == "QQVGA") framesize = FRAMESIZE_QQVGA;
  else if (cam_resolution == "96X96") framesize = FRAMESIZE_96X96;
  s->set_framesize(s, framesize);

  // 2. Quality
  s->set_quality(s, cam_quality);

  // 3. Image Tuning
  s->set_brightness(s, cam_brightness);
  s->set_contrast(s, cam_contrast);
  s->set_saturation(s, cam_saturation);

  // 4. AWB, AEC, AGC
  s->set_whitebal(s, cam_awb ? 1 : 0);
  s->set_awb_gain(s, cam_awb ? 1 : 0);
  s->set_exposure_ctrl(s, cam_aec ? 1 : 0);
  s->set_gain_ctrl(s, cam_agc ? 1 : 0);

  // 5. Mirror & Flip
  s->set_hmirror(s, cam_hmirror ? 1 : 0);
  s->set_vflip(s, cam_vflip ? 1 : 0);

  // 6. Special Effect
  int effectVal = 0;
  if (cam_specialEffect == "Negative") effectVal = 1;
  else if (cam_specialEffect == "Grayscale") effectVal = 2;
  else if (cam_specialEffect == "Red Tint") effectVal = 3;
  else if (cam_specialEffect == "Green Tint") effectVal = 4;
  else if (cam_specialEffect == "Blue Tint") effectVal = 5;
  else if (cam_specialEffect == "Sepia") effectVal = 6;
  s->set_special_effect(s, effectVal);

  // 7. XCLK (set via LEDC timer, value in MHz)
  s->set_xclk(s, LEDC_TIMER_0, cam_xclk / 1000000);

  Serial.println("[CAM] Camera configurations successfully applied to sensor.");
}

// Map angle (0-180) to Duty Cycle (13-bit: 0-8191)
// Standard Servo: 500us (0 deg) to 2400us (180 deg) at 20ms period (50Hz)
// 500us / 20000us * 8192 = 205
// 2400us / 20000us * 8192 = 983
void setServoAngle(uint8_t angle) {
  if (angle > 180) angle = 180;
  
  // Invert servo PWM control: 0 maps to 983, 180 maps to 205
  int duty = map(angle, 0, 180, 983, 205);
  ledcWrite(SERVO_PIN, duty); // Use PIN directly in Core 3.x
  // Serial.printf("[SERVO] Angle set to %d (Duty: %d)\n", angle, duty); // Removed for deployment
}

void servoTask(void * pvParameters) {
  for (;;) {
    int mode = __atomic_load_n(&sweepMode, __ATOMIC_SEQ_CST);
    bool returning = __atomic_load_n(&sweepReturning, __ATOMIC_SEQ_CST);
    int target = __atomic_load_n(&targetServoAngle, __ATOMIC_SEQ_CST);
    int current = __atomic_load_n(&currentServoAngle, __ATOMIC_SEQ_CST);

    if (mode == 1 || mode == 2 || returning) {
      int nextAngle = current;
      
      if (returning) {
        // Move towards default angle (SERVO_POS_DEFAULT) at 1 degree step
        if (current < SERVO_POS_DEFAULT) {
          nextAngle += 1;
        } else if (current > SERVO_POS_DEFAULT) {
          nextAngle -= 1;
        }
        
        if (nextAngle == SERVO_POS_DEFAULT) {
          __atomic_store_n(&sweepMode, 0, __ATOMIC_SEQ_CST);
          __atomic_store_n(&targetServoAngle, SERVO_POS_DEFAULT, __ATOMIC_SEQ_CST);
          __atomic_store_n(&sweepReturning, false, __ATOMIC_SEQ_CST);
          __atomic_store_n(&sweepDirectionUp, true, __ATOMIC_SEQ_CST);
          __atomic_store_n(&pendingSweepStopReport, true, __ATOMIC_SEQ_CST);
        }
      } else {
        // Normal active sweep (continuous or once) at 1 degree step
        bool dirUp = __atomic_load_n(&sweepDirectionUp, __ATOMIC_SEQ_CST);
        if (dirUp) {
          nextAngle += 1;
          if (nextAngle >= 180) {
            nextAngle = 180;
            __atomic_store_n(&sweepDirectionUp, false, __ATOMIC_SEQ_CST);
          }
        } else {
          nextAngle -= 1;
          if (nextAngle <= 0) {
            nextAngle = 0;
            if (mode == 2) {
              // Start returning phase at 1 degree step
              __atomic_store_n(&sweepReturning, true, __ATOMIC_SEQ_CST);
              __atomic_store_n(&sweepDirectionUp, true, __ATOMIC_SEQ_CST); // to pan back up
            } else {
              // Continuous: wrap back to up direction
              __atomic_store_n(&sweepDirectionUp, true, __ATOMIC_SEQ_CST);
            }
          }
        }
      }

      __atomic_store_n(&currentServoAngle, nextAngle, __ATOMIC_SEQ_CST);
      setServoAngle(nextAngle);
      
      // Keep target synchronized to prevent snap-back on stop (except when returning is active)
      if (__atomic_load_n(&sweepMode, __ATOMIC_SEQ_CST) > 0 && !__atomic_load_n(&sweepReturning, __ATOMIC_SEQ_CST)) {
        __atomic_store_n(&targetServoAngle, nextAngle, __ATOMIC_SEQ_CST);
      }

      vTaskDelay(pdMS_TO_TICKS(250));
    } else if (current != target) {
      int diff = target - current;
      int nextAngle = current;
      if (abs(diff) <= 5) {
        nextAngle = target;
      } else {
        if (diff > 0) {
          nextAngle += 5;
        } else {
          nextAngle -= 5;
        }
      }

      __atomic_store_n(&currentServoAngle, nextAngle, __ATOMIC_SEQ_CST);
      setServoAngle(nextAngle);

      vTaskDelay(pdMS_TO_TICKS(50));
    } else {
      // Suspend itself to save CPU cycles when target is reached
      vTaskSuspend(NULL);
    }
  }
}

void setTargetAngle(int angle) {
  if (angle < 0) angle = 0;
  if (angle > 180) angle = 180;

  __atomic_store_n(&targetServoAngle, angle, __ATOMIC_SEQ_CST);

  if (servoTaskHandle != NULL) {
    vTaskResume(servoTaskHandle);
  }
}

void ledTask(void * pvParameters) {
  int lastWrittenState = -1;
  for (;;) {
    int state = __atomic_load_n(&ledNotificationState, __ATOMIC_SEQ_CST);
    if (state == 1) {
      lastWrittenState = 1;
      // 1 slow blink: 1000ms ON (3% PWM), 1000ms OFF
      ledcWrite(FLASH_GPIO_NUM, 8);
      for (int i = 0; i < 10; i++) {
        vTaskDelay(pdMS_TO_TICKS(100));
        if (__atomic_load_n(&ledNotificationState, __ATOMIC_SEQ_CST) != 1) break;
      }
      state = __atomic_load_n(&ledNotificationState, __ATOMIC_SEQ_CST);
      ledcWrite(FLASH_GPIO_NUM, 0);
      if (state == 1) {
        for (int i = 0; i < 10; i++) {
          vTaskDelay(pdMS_TO_TICKS(100));
          if (__atomic_load_n(&ledNotificationState, __ATOMIC_SEQ_CST) != 1) break;
        }
      }
    } else if (state == 2) {
      lastWrittenState = 2;
      // 2 fast blink: ON 200ms (3% PWM), OFF 200ms, ON 200ms, OFF 200ms, Pause 1000ms
      ledcWrite(FLASH_GPIO_NUM, 8);
      for (int i = 0; i < 2; i++) {
        vTaskDelay(pdMS_TO_TICKS(100));
        if (__atomic_load_n(&ledNotificationState, __ATOMIC_SEQ_CST) != 2) break;
      }
      ledcWrite(FLASH_GPIO_NUM, 0);
      for (int i = 0; i < 2; i++) {
        vTaskDelay(pdMS_TO_TICKS(100));
        if (__atomic_load_n(&ledNotificationState, __ATOMIC_SEQ_CST) != 2) break;
      }
      if (__atomic_load_n(&ledNotificationState, __ATOMIC_SEQ_CST) == 2) {
        ledcWrite(FLASH_GPIO_NUM, 8);
        for (int i = 0; i < 2; i++) {
          vTaskDelay(pdMS_TO_TICKS(100));
          if (__atomic_load_n(&ledNotificationState, __ATOMIC_SEQ_CST) != 2) break;
        }
        ledcWrite(FLASH_GPIO_NUM, 0);
        for (int i = 0; i < 10; i++) {
          vTaskDelay(pdMS_TO_TICKS(100));
          if (__atomic_load_n(&ledNotificationState, __ATOMIC_SEQ_CST) != 2) break;
        }
      } else {
        ledcWrite(FLASH_GPIO_NUM, 0);
      }
    } else {
      if (lastWrittenState != 0) {
        ledcWrite(FLASH_GPIO_NUM, 0);
        lastWrittenState = 0;
      }
      vTaskDelay(pdMS_TO_TICKS(100));
    }
  }
}

WebSocketsClient webSocket;
bool isConnected = false;
unsigned long lastWebSocketConnectedTime = 0;
unsigned long lastSignalSent = 0;
unsigned long lastHeartbeatSent = 0;
unsigned long lastWsActivity = 0;
unsigned long lastForceReconnectTime = 0;
IPAddress serverIP;
unsigned long lastDiscoveryQuery = 0;
String globalCustomSubnet = "192.168.1";
WiFiUDP udp;
bool udpStreamEnabled = false;
bool udpInitialized = false;

// UDP transmission control
const unsigned long UDP_TIMEOUT_MS = 2000;
const unsigned long WS_LIVENESS_TIMEOUT_MS = 45000;

uint8_t* wsPacketBuffer = nullptr;

void markWebSocketAlive() {
  lastWsActivity = millis();
}

void forceWebSocketReconnect(const char* reason) {
  if (!isConnected) return;
  Serial.printf("[WSc] Connection considered stale (%s). Forcing reconnect...\n", reason);
  isConnected = false;
  lastWsActivity = 0;
  udpInitialized = false;
  webSocket.disconnect();
  lastDiscoveryQuery = 0;
  lastForceReconnectTime = millis(); // Prevent immediate reconnect (let close propagate)
}

bool sendWsText(String message, const char* context) {
  bool sent = webSocket.sendTXT(message);
  if (!sent) {
    Serial.printf("[WSc] Failed to send text message (%s).\n", context);
    forceWebSocketReconnect(context);
  }
  return sent;
}

bool sendWsBinary(uint8_t* payload, size_t length, const char* context) {
  bool sent = webSocket.sendBIN(payload, length);
  if (!sent) {
    Serial.printf("[WSc] Failed to send binary chunk (%s).\n", context);
    forceWebSocketReconnect(context);
  }
  return sent;
}
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
void loop() {
  if (WiFi.status() == WL_CONNECTED) {
    if (pendingConnectionRestart) {
      pendingConnectionRestart = false;
      Serial.println("[WSc] Restarting WebSocket connection due to UDP stream mode change...");
      webSocket.disconnect();
    }
    webSocket.loop();

    if (isConnected && lastWsActivity > 0 && millis() - lastWsActivity > WS_LIVENESS_TIMEOUT_MS) {
      forceWebSocketReconnect("heartbeat timeout");
    }

    // If WebSocket is disconnected, try to discover backend IP periodically via UDP unicast
    // Add guard: don't attempt reconnect too soon after a forced disconnect (let close propagate)
    if (!isConnected && millis() - lastForceReconnectTime > 2000) {
      if (millis() - lastDiscoveryQuery > 10000) {
        Serial.println("[DISC] WebSocket disconnected. Sweeping network for backend...");
        __atomic_store_n(&ledNotificationState, LED_STATE_FINDING_SERVER, __ATOMIC_SEQ_CST);
        IPAddress newIP = discoverBackendIP();
        lastDiscoveryQuery = millis(); // Reset timer AFTER the scan finishes
        
        if (newIP.toString() != "0.0.0.0") {
          if (newIP != serverIP) {
            Serial.printf("[DISC] Backend IP changed from %s to %s\n", serverIP.toString().c_str(), newIP.toString().c_str());
            serverIP = newIP;
          }
          // Always try reconnecting if discovered
          connectWebSocket();
        } else {
          Serial.println("[DISC] Backend discovery failed during reconnect.");
        }
      }
    }
  }

  if (isConnected) {
    lastWebSocketConnectedTime = millis();
  }

  // Failsafe reboot if disconnected or unable to connect for more than 120 seconds
  // (increased from 30s — the new heartbeat mechanism handles connection health more precisely)
  if (millis() - lastWebSocketConnectedTime > 120000) {
    Serial.println("[FAILSAFE] WebSocket disconnected or unable to connect for 120 seconds! Rebooting...");
    delay(1000);
    ESP.restart();
  }

  if (!isConnected) {
    delay(50);
    return;
  }

  // Proses on-demand capture DI SINI (di main loop, bukan di WS callback)
  // agar webSocket.loop() bisa bekerja normal selama flush buffer

  if (pendingCaptureLabel != "") {
    String label = pendingCaptureLabel;
    pendingCaptureLabel = "";
    captureAndUpload(label);
  }

  // Proses servo move
  if (pendingServoAngle != -1) {
    int angle = pendingServoAngle;
    pendingServoAngle = -1; // Reset
    setTargetAngle(angle);
  }

  // Proses pending motion reports secara thread-safe dari pirTask
  // Hanya broadcast setelah servo mencapai posisi target sensor PIR tersebut
  int currentAngleVal = __atomic_load_n(&currentServoAngle, __ATOMIC_SEQ_CST);

  bool leftTriggered = __atomic_load_n(&pendingLeftMotion, __ATOMIC_SEQ_CST);
  bool middleTriggered = __atomic_load_n(&pendingMiddleMotion, __ATOMIC_SEQ_CST);
  bool rightTriggered = __atomic_load_n(&pendingRightMotion, __ATOMIC_SEQ_CST);

  bool reportLeft = false;
  bool reportMiddle = false;
  bool reportRight = false;

  if (leftTriggered && currentAngleVal == SERVO_POS_LEFT) {
    __atomic_store_n(&pendingLeftMotion, false, __ATOMIC_SEQ_CST);
    reportLeft = true;
  }
  if (middleTriggered && currentAngleVal == SERVO_POS_MIDDLE) {
    __atomic_store_n(&pendingMiddleMotion, false, __ATOMIC_SEQ_CST);
    reportMiddle = true;
  }
  if (rightTriggered && currentAngleVal == SERVO_POS_RIGHT) {
    __atomic_store_n(&pendingRightMotion, false, __ATOMIC_SEQ_CST);
    reportRight = true;
  }

  if (reportLeft || reportMiddle || reportRight) {
    String detectedSensor = reportLeft ? "left" : (reportMiddle ? "middle" : "right");
    Serial.printf("Servo reached target angle for PIR: %s. Broadcasting motion trigger.\n", detectedSensor.c_str());
    if (WiFi.status() == WL_CONNECTED) {
      String msg = "{\"type\":\"motion\",\"sensor\":\"" + detectedSensor + "\"}";
      sendWsText(msg, "motion event");
    }
  }

  // Debug: Print pin states every 2 seconds (Removed for deployment to prevent CPU stall)
  /*
  if (millis() - lastPinDebug > 2000) {
    lastPinDebug = millis();
    Serial.printf("PIR Raw: L=%d, M=%d, R=%d\n", 
                  digitalRead(left_pir_pin), 
                  digitalRead(middle_pir_pin), 
                  digitalRead(right_pir_pin));
  }
  */

  if (isConnected && WiFi.status() == WL_CONNECTED) {    
    bool reportStop = __atomic_exchange_n(&pendingSweepStopReport, false, __ATOMIC_SEQ_CST);
    if (reportStop) {
      sendWsText("{\"type\":\"sweep_status\",\"value\":\"off\"}", "sweep stop");
      Serial.println("[WS] Sent sweep stop report to backend");
    }

    // Send independent app-layer heartbeat every 5 seconds as proof-of-life
    if (millis() - lastHeartbeatSent > 5000) {
      lastHeartbeatSent = millis();
      sendWsText("{\"type\":\"heartbeat\"}", "app heartbeat");
    }

    // Send signal strength every 8 seconds
    if (millis() - lastSignalSent > 8000) {
      lastSignalSent = millis();
      long rssi = WiFi.RSSI();
      String msg = "{\"type\":\"signal\",\"rssi\":" + String(rssi) + "}";
      sendWsText(msg, "signal heartbeat");
      // Serial.printf("Signal: %ld dBm\n", rssi); // Removed for deployment
    }

    // Ambil frame untuk dikirim ke kiosk
    camera_fb_t * fb = esp_camera_fb_get();
    if (!fb) {
      // Buffer sedang dipakai (misal saat captureAndUpload), skip frame ini
      delay(10);
      return;
    }

    // Kirim frame JPEG ke kiosk via WebSocket atau UDP (strictly according to configuration)
    bool useUdp = udpStreamEnabled;

    bool sent = false;
    if (useUdp) {
      if (!udpInitialized) {
        if (udp.begin(3001)) {
          Serial.println("[UDP] Local socket bound to port 3001");
          udpInitialized = true;
        } else {
          Serial.println("[UDP] Failed to bind local socket!");
        }
      }
      
      if (udpInitialized) {
        sent = sendFrameChunks(fb, true);
      }
    }

    if (!sent) {
      sendFrameChunks(fb, false);
    }
    esp_camera_fb_return(fb);
  }
}

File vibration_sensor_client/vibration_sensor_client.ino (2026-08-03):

#include <WiFiUdp.h>
#include <HTTPClient.h>
#include <WiFi.h>

#define SENSOR_PIN 0 // Menggunakan pin 0 untuk SW420
#define BUZZER_PIN 2 // Pin untuk Buzzer
#define RELAY_PIN 1  // Pin untuk Relay 2 Channel 12V

#define DEBUG_LED_PIN 8 // Pin 8 is the standard built-in LED for ESP32-C3 SuperMini.

// ================= DEBUG LED TASK =================
enum LedNotificationState {
  LED_STATE_OFF = 0,
  LED_STATE_CONNECTING_WIFI = 1,
  LED_STATE_FINDING_SERVER = 2
};
volatile int ledNotificationState = LED_STATE_OFF;

void setDebugLed(bool on) {
  if (DEBUG_LED_PIN == SENSOR_PIN) return; // Prevent breaking pin config if pins conflict
  // C3 SuperMini LED is active LOW (0 = ON, 255 = OFF)
  analogWrite(DEBUG_LED_PIN, on ? 0 : 255);
}

void ledTask(void * pvParameters) {
  if (DEBUG_LED_PIN != SENSOR_PIN) {
    pinMode(DEBUG_LED_PIN, OUTPUT);
    digitalWrite(DEBUG_LED_PIN, HIGH); // Start OFF
  }
  
  int lastWrittenState = -1;
  for (;;) {
    int state = __atomic_load_n(&ledNotificationState, __ATOMIC_SEQ_CST);
    if (state == LED_STATE_CONNECTING_WIFI) {
      lastWrittenState = 1;
      // 1 slow blink: 1000ms ON, 1000ms OFF
      setDebugLed(true);
      for (int i = 0; i < 10; i++) {
        vTaskDelay(pdMS_TO_TICKS(100));
        if (__atomic_load_n(&ledNotificationState, __ATOMIC_SEQ_CST) != LED_STATE_CONNECTING_WIFI) break;
      }
      state = __atomic_load_n(&ledNotificationState, __ATOMIC_SEQ_CST);
      setDebugLed(false);
      if (state == LED_STATE_CONNECTING_WIFI) {
        for (int i = 0; i < 10; i++) {
          vTaskDelay(pdMS_TO_TICKS(100));
          if (__atomic_load_n(&ledNotificationState, __ATOMIC_SEQ_CST) != LED_STATE_CONNECTING_WIFI) break;
        }
      }
    } else if (state == LED_STATE_FINDING_SERVER) {
      lastWrittenState = 2;
      // 2 fast blinks
      setDebugLed(true);
      for (int i = 0; i < 2; i++) {
        vTaskDelay(pdMS_TO_TICKS(100));
        if (__atomic_load_n(&ledNotificationState, __ATOMIC_SEQ_CST) != LED_STATE_FINDING_SERVER) break;
      }
      setDebugLed(false);
      for (int i = 0; i < 2; i++) {
        vTaskDelay(pdMS_TO_TICKS(100));
        if (__atomic_load_n(&ledNotificationState, __ATOMIC_SEQ_CST) != LED_STATE_FINDING_SERVER) break;
      }
      if (__atomic_load_n(&ledNotificationState, __ATOMIC_SEQ_CST) == LED_STATE_FINDING_SERVER) {
        setDebugLed(true);
        for (int i = 0; i < 2; i++) {
          vTaskDelay(pdMS_TO_TICKS(100));
          if (__atomic_load_n(&ledNotificationState, __ATOMIC_SEQ_CST) != LED_STATE_FINDING_SERVER) break;
        }
        setDebugLed(false);
        for (int i = 0; i < 10; i++) {
          vTaskDelay(pdMS_TO_TICKS(100));
          if (__atomic_load_n(&ledNotificationState, __ATOMIC_SEQ_CST) != LED_STATE_FINDING_SERVER) break;
        }
      } else {
        setDebugLed(false);
      }
    } else {
      lastWrittenState = 0;
      if (DEBUG_LED_PIN != SENSOR_PIN) {
        setDebugLed(false);
      }
      vTaskDelay(pdMS_TO_TICKS(100)); // Update at 10Hz
    }
  }
}

// ================= WIFI =================
const char *ssid = "Tenda03";
const char *password = "BRHtenda68";

// ================= GATEWAY (UDP DISCOVERY) =================
String globalCustomSubnet = "192.168.1";
String resolvedGatewayIP = "";          // Menyimpan IP hasil resolve
const int backendPort = 3000; // GANTI dengan port backend Node.js Anda

// ================= IDENTITAS NODE =================
const String nodeLocation = "Pagar_Utara";
const String sensorName = "Node_01";

// ================= DEBOUNCE =================
const int REQUIRED_CONSECUTIVE_READS =
    1; // Harus 4x berturut-turut putus (1 detik) untuk mengirim alert
const int REQUIRED_CONSECUTIVE_NORMAL =
    1; // Harus 4x berturut-turut normal (1 detik) untuk me-reset status

int cutCounter = 0;
int normalCounter = 0;
bool alertSent = false;

// ================= TIMER RELAY =================
unsigned long relayStartTime = 0;
bool relayActive = false;
const unsigned long RELAY_DURATION = 30000; // 30 detik (30000 ms)

// ================= WIFI =================
void connectWiFi() {
  Serial.print("Connecting WiFi");

  WiFi.mode(WIFI_STA);
  WiFi.begin(ssid, password);

  while (WiFi.status() != WL_CONNECTED) {
    delay(500);
    Serial.print(".");
  }

  Serial.println();
  Serial.println("WiFi Connected");
  Serial.print("IP: ");
  Serial.println(WiFi.localIP());
  
  __atomic_store_n(&ledNotificationState, LED_STATE_FINDING_SERVER, __ATOMIC_SEQ_CST);
}
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

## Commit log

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2026-05-13 ganti label list device dengan mac addres dan simplifikasi label live feed
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2026-05-14 bring back mdns resolver to esp32cam and telegram notifier didnt work
    [camera_client_ws.ino]
2026-05-15 feat: implement high-resolution snapshot capture on ESP32-CAM and update backend to serve and display motion images
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2026-05-15 refactor: adjust camera brightness and disable high-resolution snapshot configuration in camera client
2026-05-17 added camera switch button for mobile view and dummy servo control button
2026-05-17 feat(websocket): tambah getDevices(), sendCaptureRequest(), dan simpan referensi ws
    - Ekspor fungsi getDevices() agar state kamera aktif bisa diakses dari modul lain
    - Ekspor fungsi sendCaptureRequest(deviceId) untuk mengirim perintah capture
    ke kamera tertentu via WebSocket dari perintah Telegram /capture
    - Simpan referensi WebSocket client (ws) di dalam Map devices agar
    sendCaptureRequest dapat langsung mengirim pesan ke kamera yang dituju
    - Hapus panggilan sendMotionAlert dari handler motion event; alert Telegram
    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
2026-05-17 feat(routes): integrasikan alert Telegram setelah foto tersimpan di disk
    - Tambah import notifyCaptureResult dari telegram.js
    - Pisahkan alur upload berdasarkan sensor:
    * sensor='capture' (on-demand Telegram): panggil notifyCaptureResult(filepath)
    agar foto langsung dikirim ke pengguna yang menunggu
    * sensor lainnya (PIR motion): update log, kirim sendMotionAlert dengan
    filepath foto yang baru saja disimpan, broadcast ke kiosk
    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
2026-05-17 feat(telegram): implementasi bot dengan fitur lengkap multi-pengguna
    Perintah baru:
    - /devices: menampilkan daftar kamera ESP32-CAM yang terhubung beserta
    status online/offline, sinyal WiFi, IP, dan waktu terakhir aktif
    - /capture: trigger pengambilan foto on-demand dari kamera yang dipilih;
    mendukung inline keyboard jika lebih dari satu kamera aktif
    - /getimage DD MM YY: filter log.json berdasarkan tanggal dan tampilkan
    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
2026-05-17 refactor(config): pindahkan config.json ke folder /data
    - Pindahkan config.json dari root project ke /data agar semua
    file persisten (config, log, foto) berada di satu folder yang sama
    - Update configPath di telegram.js dari '../../../config.json'
    menjadi '../../../data/config.json'
2026-05-17 fix(firmware): atasi flicker garis horizontal di live feed
    Masalah: garis horizontal muncul di live feed akibat dua hal:
    1. Banding 50Hz PLN — AEC tidak tersinkron dengan frekuensi listrik Indonesia
    2. Fragmentasi WiFi — rate streaming terlalu tinggi (delay 10ms = ~100fps attempt)
    Solusi:
    - XCLK streaming diturunkan ke 10MHz (dari 20MHz) untuk resolusi
    HVGA/VGA/SVGA. XCLK lebih lambat membuat shutter speed proporsional
    lebih panjang sehingga sensor kurang sensitif terhadap banding 50Hz PLN
    - XCLK capture FHD tetap 20MHz agar bandwidth sensor tetap tinggi
    - Logika XCLK otomatis dipilih di reinitCamera() berdasarkan resolusi
    - jpeg_quality streaming ditingkatkan dari 10 ke 8 untuk men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
    [camera_client_ws.ino]
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2026-05-17 fixed the issue where event log images were not appearing on your smartphone or Raspberry Pi.
    Why this was happening:
    The backend was hardcoding the address https://gateway.local:3000/... into the image URLs. Many smartphones and the Raspberry Pi's default configuration cannot resolve .local addresses
    (mDNS) reliably, so they would fail to load the images even if the rest of the app was working.
    The Fix:
    1. Backend Optimization: Updated the backend to send "host-agnostic" relative paths (e.g., /data/image.jpg) instead of hardcoded full URLs.
    2. Frontend Intelligence: Added a getImageUrl helper in the kiosk frontend.
    * It detects if you are using an IP address or gateway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
2026-05-17 implemented ICMP pings to monitor the status of your ESP32-CAM devices more reliably.
    Key Implementation Details:
    1. Network-Level Monitoring: The backend now uses the standard system ping command (ICMP) to check if the camera's IP address is reachable on the network.
    2. Stable Heartbeat: Every 30 seconds, the backend pings each connected camera.
    * If the ping succeeds: The camera is kept online. This avoids the "false positive" disconnections that can happen with low-level WebSocket frames if the ESP32 is busy.
    * If the ping fails: The camera is immediately marked as Offline in the dashboard and its WebSocket connection is terminated to clean up the session.
    3. Hybr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
2026-05-17 replaced the ICMP/WebSocket ping system for the cameras with a Stream-Activity Heartbeat.
    How it works now:
    1. Direct Data Monitoring: The backend now tracks the exact millisecond each camera sends a video frame (mjpeg data).
    2. 5-Second proof-of-life: Every 5 seconds, the backend checks all camera connections.
    * If a camera is streaming: It stays "Online".
    * If no data is received for 5 seconds: The backend considers the camera "frozen" or disconnected, marks it as Offline in the dashboard, and terminates its connection to free up
    resources.
    3. Dynamic Response: This is much more accurate than a network ping, as it guarantees that a camera shown as "Online"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
2026-05-18 PSRAM Pre-allocation strategy to fix the camera probe failures.
    What has changed:
    1. Boot-time Reservation: During setup(), the camera now initializes at Full HD (FHD) resolution. This forces the ESP32 to reserve the large blocks of memory it needs right at the
    start when PSRAM is empty.
    2. Instant Downscaling: Immediately after boot, the system uses the sensor API to downscale to HVGA for streaming. This keeps the WiFi bandwidth low while keeping the large memory
    buffer "reserved" in the background.
    3. Seamless Switching: In captureAndUpload, we no longer deinit the driver. We simply tell the sensor to switch to FHD, take the photo, and then switch back to HVGA.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
    [camera_client_ws.ino]
2026-05-18 updated the UI to include a functional servo slider and repositioned the controls for better mobile ergonomics.
    Changes Made:
    1. Reorganized Mobile Layout:
    * Changed the side-by-side col-6 layout to a vertical stack.
    * Camera Switch buttons are now at the top.
    * Servo (PTZ) controls are positioned directly below the camera buttons with increased spacing (gap-4) for better touch clarity.
    2. Implemented Servo Slider:
    * Replaced the dummy "Left/Right" buttons with a horizontal range slider (0° to 180°).
    * Added a real-time degree badge ({{ servoValue }}°) that updates as you slide.
    * Added visual markers for 0°, 90°, and 180° below the sli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
2026-05-18 implement WebSocket-based remote servo motor control via Kiosk dashboard and backend relay
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2026-05-18 unified the servo configuration system by migrating it entirely to WebSockets.
    Key Achievements:
    1. Unified Protocol: Removed the separate HTTP REST endpoints and integrated the saving and loading of configurations into the existing WebSocket bridge. This reduces network overhead
    and eliminates the need for separate CORS management for configuration tasks.
    2. Responsive Loading: The system now fetches saved settings (Default Angle, PIR Zones) via the socket the moment you open the configuration modal, ensuring the UI always reflects the
    actual server state.
    3. Advanced UI Controls:
    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
2026-05-18 feat: integrate servo movement with PIR sensor motion detection using predefined position constants
2026-05-18 feat: implement dynamic servo configuration updates via WebSocket synchronization between backend and camera client
2026-05-18 fix: invert servo PWM mapping and update JSON keys for configuration parameters
    [camera_client_ws.ino]
2026-05-18 dded a really cool 69-degree FOV Visualizer to your Servo Configurator UI!
    Here is how it works:
    Right below the degree ticks (0° to 180°), there is now a dedicated dark box labeled 69° FOV VISUALIZER.
    As you drag the left, middle, or right sliders, it dynamically generates an upward-facing "cone of vision" (simulating a flashlight or camera view) that perfectly matches the 69-degree width scaling.
    The cones are color-coded (red, green, blue) to match the slider thumbs.
    I used a mix-blend-mode: screen effect on the transparent gradients, which means that wherever the fields of view overlap, the colors will beautifully mix and brighten up, instantly showing you exact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
2026-05-18 efactored that code for you to make it modular.
    Here's what I did:
    Created a new component: I made a new file called ServoConfiguratorModal.vue in the same directory.
    Moved the Logic: I extracted all the complex multi-thumb slider logic, the FOV visualizer, the WebSocket event listeners (servo_config_received), and the modal UI elements out of StreamView.vue and p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
    Cleaned up StreamView: StreamView.vue now just imports the <ServoConfiguratorModal> tag and passes down the mac address prop. It listens for a @save event to handle the actual WebSocket transmission,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
    Preserved Style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
2026-05-19 feat: add Raspberry Pi deployment guide, support multiple camera sensor resolutions, and allow host in Vite configuration
2026-05-20 added the hardcoded API key security to both the ESP32-CAM and the backend.
    Changes Summary:
    1. Backend (backendAndTelegramBot/src/websocket.js):
    * Defined CAMERA_API_KEY = 'momo_gemoy_api_key_123'.
    * Implemented a handshake check for requests to /camera. If the x-api-key header is missing or incorrect, the connection is
    immediately terminated with a security warning logged to the console.
    2. ESP32-CAM (camera_client_ws/camera_client_ws.ino):
    * Added apiKey = "momo_gemoy_api_key_123" to the global constants.
    * Updated the WebSocket initialization to send both X-MAC-Address and X-API-Key headers during the handshake.
    [camera_client_ws.ino]
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2026-05-20 added the management commands to your Telegram bot.
    New Commands:
    1. /listids: Lists all currently registered Chat IDs that receive motion alerts.
    2. /deleteid <id>: Removes a specific Chat ID from the notification list.
    * Example: /deleteid 123456789
    3. Updated /start: The welcome message now includes these new commands in the help list.
    Security Note:
    I added a check so that only users who are already registered can use /listids and /deleteid. This prevents strangers from messing with your notification settings.
    All changes are saved persistently in data/config.json.
2026-05-20 implementing the Telegram authentication system. Your bot is now secured with a password gate.
    What has been done:
    1. Password Gate: Any user who hasn't been registered yet will be blocked from using any commands and will be asked for a password.
    2. Auto-Registration: Once the correct password is sent, the bot automatically saves that user's ID to data/config.json.
    3. Command Cleanup: Removed the manual /register_this_id command since registration is now automatic upon successful login.
    ⚠️ Final Step Required:
    You must add your secret password to the environment variables. Open your backendAndTelegramBot/.env file and add this line:
    1 TELEGRAM_AUTH_PASSWORD=your_secre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
2026-05-24 ## Analisis Masalah
    Ada **beberapa bug kritis** di kode ini yang menyebabkan bounding box tidak muncul atau salah posisi:
    ---
    ### 🐛 Bug #1 — Parsing Output YOLOv8 Salah (Penyebab Utama)
    ```python
    # ❌ SALAH: Index 4 BUKAN confidence 'person', tapi koordinat ke-5!
    class_conf = float(row[4])
    ```
    **Format output YOLOv8 TFLite yang benar adalah:**
    - `row[0:4]` → koordinat box (cx, cy, w, h)
    - `row[4]` → bukan confidence class person, ini masih bagian koordinat jika model versi lain
    - `row[4:4+80]` → 80 class scores COCO (index 4 = class 0/person confidence)
    ```python
    # ✅ BENAR: Ambil semua class scores, cari class 0 (person)
    class_scores = row[4:] # 80 nilai class sc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
2026-05-24 uccessfully integrated real-time object detection into your ESP32-Cam kiosk project.
    The approach used is a Hybrid AI Sampling + Canvas Overlay system, which is highly efficient for the Raspberry Pi 3:
    1. AI Server (human_detection/app.py): Added a /detectJSON endpoint that returns only raw bounding box coordinates. This skips the heavy process of drawing on the image and
    re-encoding it to JPEG in Python.
    2. Node.js Backend (websocket.js): Implemented a sampling mechanism that sends one frame per second (1 FPS) to the AI server without blocking the main live stream. The resulting
    coordinates are broadcasted via WebSocket.
    3. Vue Frontend (StreamView.vue & KioskDashboa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
2026-05-24 cameraKiosk/src/components/KioskDashboard.vue, the <StreamView> component is trying to trigger functions named handleCameraAction and handleServoAction, but those functions are actually named trigger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
    To fix this, update the <StreamView> tag inside
    cameraKiosk/src/components/KioskDashboard.vue to point to the
    correct function names.
    Replace this block (around line 208):
    1 <StreamView
    2 :currentStream="currentStream"
    3 :liveImageSrc="liveImageSrc"
    4 :liveBoxes="liveBoxes"
    5 :windowWidth="windowWidth"
    6 @triggerCameraAction="handleCameraAction"
    7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
2026-05-25 You have a logic bug in
    camera_client_ws.ino
    (lines 293–297) where the high-resolution frame sizes are accidentally swapped:
    cpp
    if (s->id.PID == OV3660_PID) {
    s->set_framesize(s, FRAMESIZE_UXGA);
    } else if (s->id.PID == OV2640_PID) {
    s->set_framesize(s, FRAMESIZE_FHD);
    }
    The Physical Limit of the OV2640: The OV2640 is a 2 Megapixel sensor with a physical silicon active pixel array of exactly 1600x1200 pixels (UXGA). It physically only has 1600 horizontal pixels on its silicon die. It is physically impossible for this sensor to capture a Full HD (1920x1080) image because 1920 exceeds its horizontal pixel limit.
    Why it Crashes: When you trigger a sensor on the OV2640, the code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
    [camera_client_ws.ino]
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2026-05-25 commented out all high-frequency print() calls in the Python AI inference service ( app.py ) for performance testing. This fully suppresses terminal logging operations during standard frame-by-frame 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
    1. Commented Out High-Frequency Prints
    app.py
    Muted [DEBUG] Skor tertinggi: ... to avoid np.max calculations and printing on every loop iteration.
    Muted [DEBUG] Mentah: ... logging inside run_tflite_inference.
    Muted Incoming request received over WebSocket timing print inside handle_client.
    Muted [INFO] Menjalankan inferensi TFLite... and [INFO] RAM dibersihkan. cleanup log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
2026-05-25 migration of the WebSocket communication between the Node.js backend and the Python AI server to a high-performance Raw Binary Stream.
    Summary of Changes
    Node.js Backend
    aiClient.js
    Binary Requests: Replaced Base64 and JSON payloads with a compact binary Buffer comprised of a 5-byte header (UInt32BE for requestId and UInt8 for annotate) and the raw binary JPEG image. Sent directly via binary socket frames.
    Binary Responses: Added custom binary parsing for annotate = true snapshots. It decodes the 8-byte header, extracts the JSON metadata block, and converts the remaining raw JPEG bytes back to a Base64 string locally on Node.js to retain 100% backward compatibility with routes.js and your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
2026-05-26 replace status badges with dynamic signal strength indicators in device dashboard
2026-05-26 (Node.js Backend) :
    Swapped out the WebSocket client initiator (new WebSocket) for a dedicated, native new WebSocketServer({ port: 5000 }).
    It now binds to port 5000 as the Server and listens for incoming connections from the Python client.
    Maintained complete backward compatibility for all promise-based frame request/response handling, status changes, and data streams.
    (Python AI)
    Replaced the local port-binding configuration variables with the target backend credentials:
    python
    BACKEND_HOST = "127.0.0.1"
    BACKEND_PORT = 5000
    (Python AI)
    Refactored main() from a server-mode listener (websockets.serve) to a robust, self-healing client connection loop (websockets.conne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
2026-05-27 feat: replace XCLK frequency dropdown with a slider and reactive display in CameraConfiguratorModal
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2026-05-29 fix: restrict bounding box broadcasts to active device and remove type field from device status payload
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2026-06-05 refactor: replace ESP32-CAM snapshots with stream-based AI annotations and asynchronous background processing
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2026-06-06 feat: standardize camera resolution and quality defaults and add reset functionality to configurator modal
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2026-06-08 fix: correct sidebar border property and remove invalid pointer-events style from save button
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2026-06-11 camera_client_ws/camera_client_ws.ino: Declared a global variable int cam_flashIntensity = 0 to preserve the configured spotlight/flash brightness. Updated the incoming camera_config_update parser to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
    [camera_client_ws.ino]
2026-06-11 Desktop Force Mobile Layout Toggle and Stream Feed Fix The Layout Feature Added a Mobile View / Normal View toggle button in the navigation header ( TopNav.vue ), visible only on screen widths greate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
2026-06-13 apalah: replace AiConfiguratorModal with SystemSettingsModal and add pixel motion detection prototype
    [camera_client_ws.ino]
2026-06-14 refactor: stabilize tracking logic with shape checks, tuned PID constants, and improved mDNS-based WebSocket reconnection
    [camera_client_ws.ino]
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2026-06-22 refactor: replace HTTPS with HTTP for internal communication and implement UDP server discovery
    [camera_client_ws.ino]
2026-06-30 fixing cat pictures on camera feed
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2026-07-04 feat: implement server-side device auto-sweep scheduling and replace manual sweep settings with configurable sweep modes
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2026-07-12 integrate ESP32C3 tripwire node, fix 5 camera column grid
2026-07-15 refactor: replace tripwire spam mechanism with static alerts, update Wi-Fi credentials, and improve event log UI for non-image entries
    [vibration_sensor_client.ino]
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2026-07-17 feat: replace servo sweep buttons with a snapping range slider
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2026-07-18 feat: replace IP addresses with device names in system notifications and update StreamView UI styling and camera sweep interval
    [camera_client_ws.ino]
2026-07-18 fix: synchronize PIR motion triggers with target servo angle
    [camera_client_ws.ino]
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
